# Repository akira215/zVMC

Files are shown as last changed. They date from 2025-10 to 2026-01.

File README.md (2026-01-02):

# zVMC
Driving ALDES controlled mechanical ventilation using Modbus, embedded sofware on dedicated PCB using ESP32C6 µC

# Description

This repository contain all the development for an electronic device that will monitor ALDES VMC Inspirair using zigbee to transmit data to a coordinator. It contains: 
 * A PCB design [PCB design](PCB/README.md)
 * An enclosure design to be printed in 3D [Enclosure design](3Dprint/README.md)
 * Source code of the embedded software on the board (in an ESP32C6 µC)
 * An External converter for Zigbee2MQTT service [external converter](external_converters)

# Principle

The board will collect data from various sensors surch as:
 * Upstream static pressure (pump side)
 * Downstream static pressure (home side) - difference between upstream and downstream static pressure is used to estimate filters clogging
 * Water level sensor, to estimate the available water volume in the tank
 * water pulse meter to count the consumption in the home
 * Additionally on board temperature sensor could be monitor

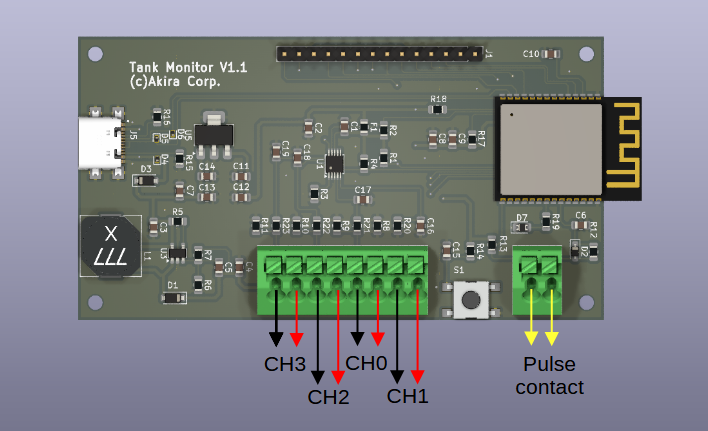
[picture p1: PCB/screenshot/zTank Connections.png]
zTank connections
 

 The 3 first sensors shall be 4-20mA sensor directly connected to the board. The water counter shall be a dry contact meter, connected to the board

 All these sensors have a calibration factor that can be updated directly form Zigbee2MQTT GUI. To avoid losing calibration, the device itself will keep updated theses factor in its Non Volatile Storage.

z2m settings (specific)

A 4-20mA input is available for any other futher sensor requirement. Adding a sensor will require to :
 * Update the embedded software
 * Update the external converter on Zigbee2MQTT side

## Usage

  * Short press button to join the zigbee network (coordinator shall grant pairing) -> LED shall flash, until network is joined, it then shutoff
  * Long press button to leave network. When the LED is fixed on, the device is not connected to the network neither is trying to join

## Sensor selection

### Upstream and downstream static pressure

  Regular pressure transmitter are not so expensive and efficient for that purpose. These 2 sensors shall have a measured range according to installation pressure. In regular network, pressure is limited to 3 bars, so selecting a sensor 0-5 bars seems a good choice. If the upper value is higher, the resolution of the measurement will be less as the ADC converter resolution is fixed.

  The shunt to convert current to tension for the ADC converter is 133R, and Imax for the sensor @max range will be 20mA so Umax for ADS1115 will be 2.66V (U=R*I). 5 bars = 500 kPa, so the calibration factor shall be 500 kPa / 2.66V = 187.97 kPa/V. Of course this factor shall be adjusted by measuring at the same location of one sensor the pressure, and correcting the reading of the sensor, but this short computation can help to start setting up calibration factor

### Water level

  Whatever technology of sensor could be used as soon as its output is 4-20mA current. Tests have been done using submerged differential pressure sensor, with the balance pipe to get the atmospheric pressure that run with the electrical cable, they worked properly. The range of this sensor shall be in accordance with the depth of the tank. The output value of Zigbee2MQTT will be a % of depth (meaning 100% when tank is full). Depending on the shape and cross section of the tank, this could be converted to a volume directly in the Z2M external converter, or outside Z2M in another software.

  The shunt to convert current to tension for the ADC converter is 133R, and Imax for the sensor @max range will be 20mA so Umax for ADS1115 will be 2.66V (U=R*I). fFr 100% the calibration factor shall be 100% / 2.66V = 37.594 %/V. Of course this factor shall be adjusted when tank is full to read 100% in the Zigbee2MQTT output.

### Water pulse counter

  The water meter shall send a pulse each XX L, whatever XX is. It is expected to have a dry contact that switch on and off each pulse. Hardware debouncer has been implemented for a particular counter, measuring bouncing using an oscilloscope. Computation of this RC filter has been provided here:
  [Spreadsheet](<PCB/2024-06-29 Comput.ods>)
    
  The kFactor to be set up in Zigbee2MQTT is only the L per pulse of the counter.

## Zigbee2MQTT integration

### External converter

External converter shall be loaded according to Zigbee2MQTT instructions:

[Zigbee2MQTT external converters](https://www.zigbee2mqtt.io/advanced/more/external_converters.html)

Restart Zigbee2MQTT `Webpage > Settings > Tools > Restart Zigbee2MQTT`

### Pairing zTank device

If the LED is fixed on, short press one time on the button, this will put the device in pairing mode.
Device is in Pairing Mode when the LED flahes quickly. 

Put Coordinator (or other device) in pairing mode using Zigbee2MQTT GUI (antenna symbol on the upper right of the screen with mention `All`)

After a short time, LED shall stop flashing. When LED is off, device is paired. You can check on Zigbee2MQTT device list

### Device icon

To add an icon in Zigbee2MQTT GUI, create a folder named `device_icon` in the root of Zigbee2MQTT docker installation (folder containing `configuration.yml`). In that foler, put the `zTank_icon.png` file contained in the `img` directory of this repository.

On Zigbee2MQTT GUI, go to `Devices` list and click on the device. Go to `Settings` tab and scroll down to the `icon` box.
Put `device_icons/zTank_icon.png` in that box. Icon shall be visible on Zigbee2MQTT GUI.

### Reporting

To develop*******************************************************************

## Build Instructions

The embedded software required `esp-ash-components`:

```
git submodule add https://github.com/akira215/esp-ash-components.git components
```

Create a partition.csv for zigbee and configure menuconfig with custom partition table (shall be done by default)

## Remote USB over IP to debug

### Server side using raspberry Pi

Install package:

```
sudo apt install usbip
```

Install drivers and let them run at start:

```
sudo -i
modprobe usbip_host
echo 'usbip_host' >> /etc/modules
```

List usb devices:

```
usbip list -l
```

Create start and stop scripts:

```
nano /usr/sbin/usbip_start.sh
```

```
#! /bin/bash

usb1='303a:1001'
# usb2='xxx'

/usr/sbin/usbip bind --$(/usr/sbin/usbip list -p -l | grep '#usbid='$usb1'#' | cut '-d#' -f1)
#/usr/sbin/usbip bind --$(/usr/sbin/usbip list -p -l | grep '#usbid='$usb2'#' | cut '-d#' -f1)

```

```
nano /usr/sbin/usbip_stop.sh
```

```
#! /bin/bash

usb1='303a:1001'
# usb2='xxx'

/usr/sbin/usbip unbind --$(/usr/sbin/usbip list -p -l | grep '#usbid='$usb1'#' | cut '-d#' -f1)
#/usr/sbin/usbip unbind --$(/usr/sbin/usbip list -p -l | grep '#usbid='$usb2'#' | cut '-d#' -f1)
killall usbipd
```

Turn them executables:

```
chmod +x /usr/sbin/usbip_start.sh
chmod +x /usr/sbin/usbip_stop.sh
```

Test the scripts:

```
. /usr/sbin/usbip_start.sh
. /usr/sbin/usbip_stop.sh
```

Create a service:

```
nano /lib/systemd/system/usbipd.service
```

```
[Unit]
Description=usbip host daemon
After=network.target

[Service]
Type=forking
ExecStart=/usr/sbin/usbipd -D
ExecStartPost=/bin/sh -c '/usr/sbin/usbip_start.sh'
ExecStop=/bin/sh -c '/usr/sbin/usbip_stop.sh'

[Install]
WantedBy=multi-user.target
```

Start the service at boot:
let system know about that service

```
systemctl --system daemon-reload
```

to start service at boot

```
systemctl enable usbipd.service
```

and start service, check status:

```
systemctl start usbipd.service
systemctl status usbipd.service
```

### Client side Windows 11

Create a restore point on the system

Install OSSign release of https://github.com/vadimgrn/usbip-win2 :

https://github.com/OSSign/vadimgrn--usbip-win2/releases

run the GUI to find the device !

## Configuration

Configuration is available in `menuconfig` in the `Project setting` section:

### Pin Layout

  This section refer to hardware connection of LED button and volume meter. <span style="color:red">**These settings shall not be changed unless new hardware is developped.**</span>

pin layout

### Zigbee endpoints

  This section refer to the endpoint for each sensor of the device. Any change in this number require to update the external converter accordingly

Zigbee endpoints

  And in Zigbee2MQTT external converter:

External converter

### Zigbee device

  Zigbee stack has been sized doing extensive tests. <span style="color:red">**This setting shall not be changed.**</span>

Zigbee device

### ADS Pin Layout

  This section refer to hardware connection of ADS1115 converter to µC pin. <span style="color:red">**These settings shall not be changed unless new hardware is developped.**</span>

ADS pin layout

### ADS Converter config

  The first 3 inputs refer to the channel in which each sensor is connected. Take care that channel are not implemented on the connector in a logical order, so please refer to pictures that describe which pins of the connector is connected to which ADC channel (and polarity for sensors)

  The delay between 2 queries of ADS is the update rate of the measurement. Between 2 measurement, ADS is put in sleep to optimize consumption. Take care that driver will trigger one conversion for each channel, so there is a minimal time between 2 queries, depending on the resolution set for the ADS.

  The delay between 2 queries of temperature is the update rate of the measurement of the internal µC temperature sensor.

ADS converter config

## Current Status

Still work in progress, but is completely running. All bugs 
could be reported to try to improve it.

## PCB design

[PCB design](PCB/README.md)

## Enclosure design design

[Enclosure design](3Dprint/README.md)

## Caveats

### To be developped

OTA update

## Usage and Examples

## Changes

### New in version 0.0.0

## Credits

 * [Zigbee2MQTT](https://github.com/Koenkk/zigbee2mqtt)

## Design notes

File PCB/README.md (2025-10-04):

# zTank PCB
A dedicated PCB using ESP32C6 µC as been designed to optimize reliability and costs.

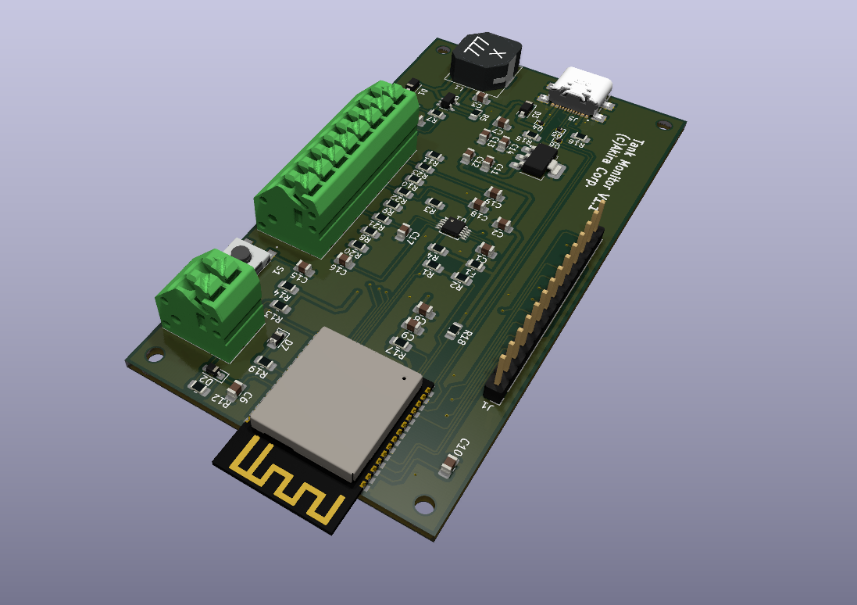
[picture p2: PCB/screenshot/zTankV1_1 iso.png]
Iso view of zTank PCB


## Tools

 The design of the PCB has been done with KiCad 9.0. Particular footprint and 3D STEP file are included in the `/footprints` folder for sake of maintenance

## Design

 The design is based on ESP32C6 WROOM with the following peripherials:
 * USB for power, flash device and output serial debug / info.
 * Powering circuit is done using MCP1826S 
 * A 4-20mA loop is built based on a LM2735X (1.6MHz) to raise voltage to about 20V
 * 4 channels 4-20mA sensors is provided and converted using ADS1115IDGS. It communicate with µC with i2c port
 * a debounced contact is provided for pulse counter
 * A push button is also provided for very simple HMI
 * PCB is also equipped by a LED for simpl HMI
 * Finally PCB is equipped with header that can be used for a touchscreen device in case of future needs (software lib already written and tested)

 Component size has been selected to 0805, except ESD protective diodes that are smaller.

### USB

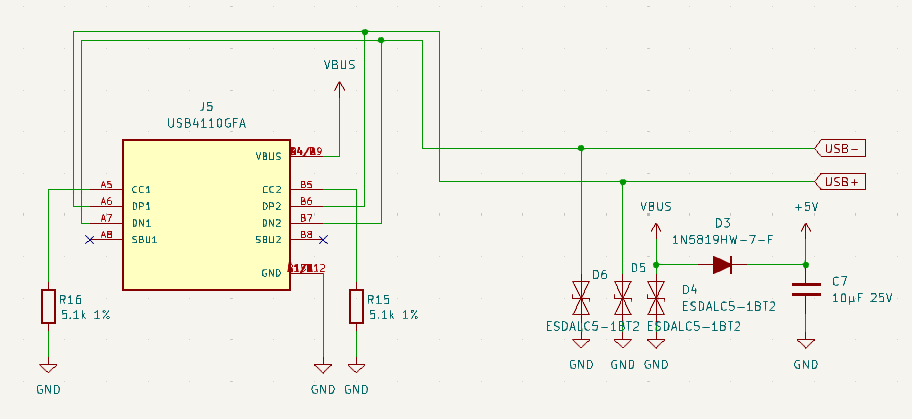
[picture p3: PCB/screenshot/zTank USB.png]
USB schematic
  

  USB socket is grounded to the main ground planes (2 sides).
  USB Lines `USB-` and `USB+` are directly connected to ESP32C6 to flash and monitor µC.
  `VBUS` is used to provide `+5V` (which is in fact lower than +5V) via a protective diode `D3`.

  All this 3 lines are protected by ESD protective diode.

### Voltage regulator

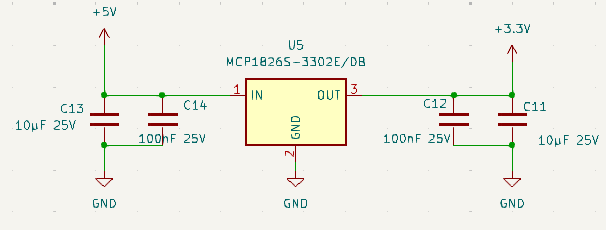
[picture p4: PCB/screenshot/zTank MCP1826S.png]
Regulator schematic
  

  All the board is powered using `+3.3V`. This voltage is provided by a fixed low-voltage regulator MCP1826S-3302E that can provide up to 1000mA.
  Fixed voltage regulator requires only few external component, in this case only capacitors are installed as per datasheet.

### 4-20mA Voltage circuit

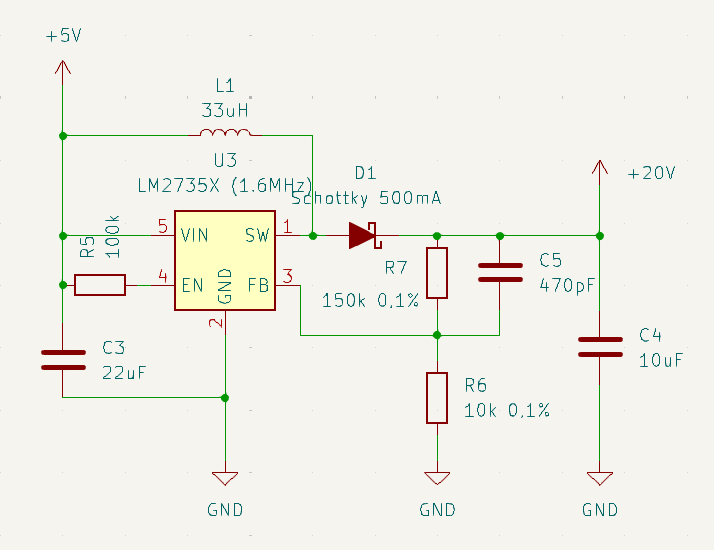
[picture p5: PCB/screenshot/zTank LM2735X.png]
LM2735X schematic
  

  To avoid noise on lines and due to voltage drop at each stage, 4-20mA loop voltage shall be at around 20V. Care shall be taken when changing this voltage as it may require adjustment (in the shunt values for instance) to avoid damaging other components.

  This voltage is produced from `+5V` using a boost type regulator LM2735X (@1.6MHz). Computation of the external components are provided in the LibreOffice Spreadsheet [PCB comput spreadsheet](<2024-06-29 Comput.ods>). A 33µH inductance has been selected to get a clean output voltage to avoid noise on sensors line.

### 4-20mA conversion

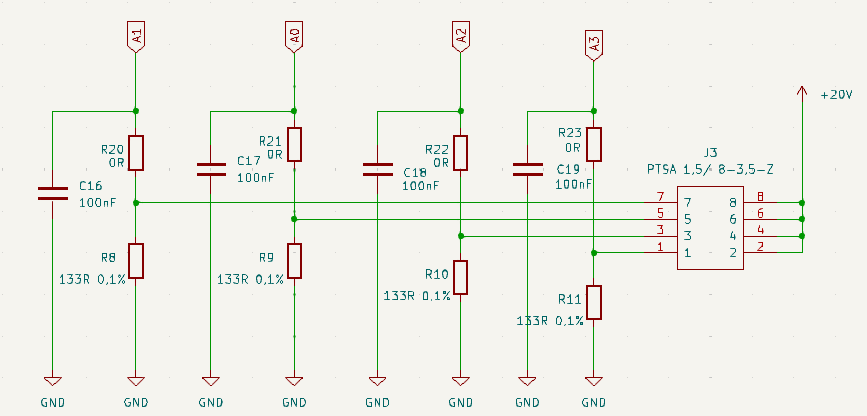
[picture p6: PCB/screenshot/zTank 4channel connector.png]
4 channel connector schematic
 

  4 channels are available via Phoenix contact 8 poles connector. Each channel input current is injected in a 133R shunt (low tolerance resistor) to output a voltage below 3.3V. A 100nF capacitor is provided to reduce noise.

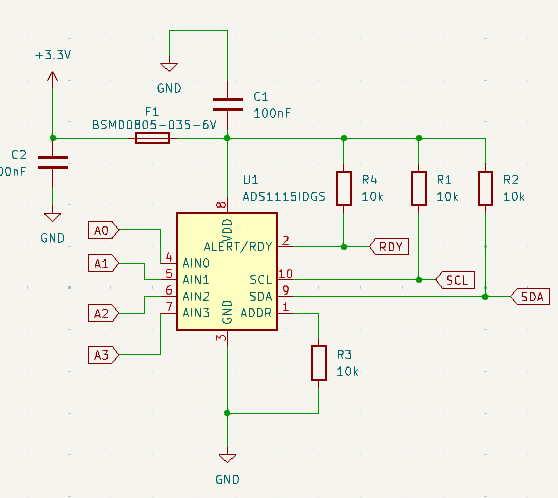
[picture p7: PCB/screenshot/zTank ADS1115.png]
ADS1115 schematic
  

  Each channel voltage is then converted in a digital signal using an ADS1115IDGS, that communicate with µC using i2c protocol. A ready pin is used to trigger an interrupt to the µC when data are available.
  External components are:
   * 10k resistor connected to the ground for the address of the device (only one on board so gnd is the common one)
   * 10k pull-up resistor on each signal (`SCL`, `SDA`, `RDY`) connected to µC
   * Decoupling capacitor for power lines and rearmable fuse to protect circuit

### Debounced contact

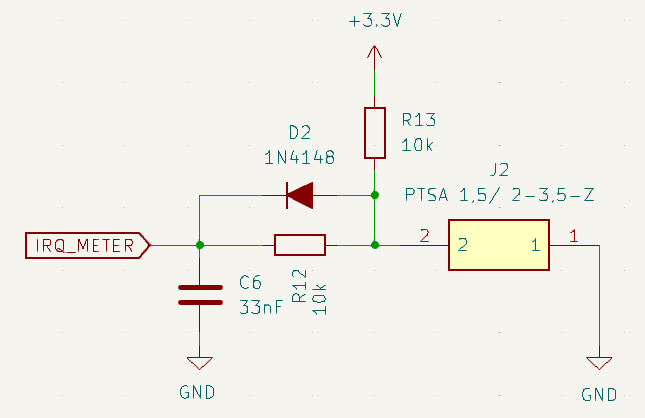
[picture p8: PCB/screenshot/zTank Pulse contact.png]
Debounced pulse schematic


An harware RC filter has been set up on this input to avoid false triggering. The computation of this filter is detailed in the spreadsheet file [PCB comput spreadsheet](<2024-06-29 Comput.ods>), bouncing duration has been measured using an oscilloscope in a unique water meter equiped with dry contact pulse output. It may be required to adjust this filter if the water meter seems to input false pulse to the µC. 

The only other component is a pull-up resistor to not let a float input.

### µC ESP32C6 WROOM

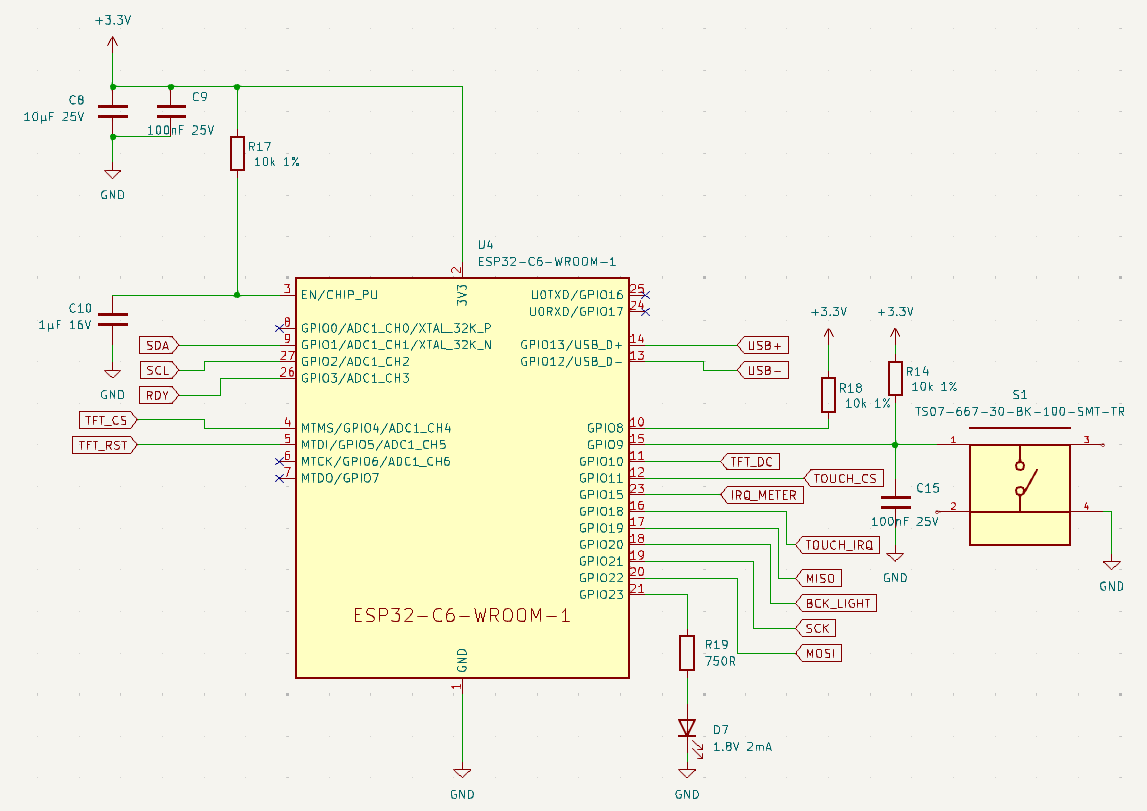
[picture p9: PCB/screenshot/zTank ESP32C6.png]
µC schematic


ESP32C6 power up is done using decoupling capacitor (10µF // 100nF).

The `EN` pin is driven to the `+3.3V` to enable the µC. 

`GPIO9` shall be pulled up to `+3.3V` to set the µC in normal execution mode (instead of ROM serial bootloader when `GPIO9` is pulled to the ground). Despite the doc says that it has an internal pull-up, µC will not boot normally after reporg if not driven to `+3.3V`.

`GPIO8` shall be driven to `+3.3V` as doc says, in order to enter the serial bootloader reliably.

### Push Button

Push button has been connected to `GPIO9`, so it can be used to boot/flash device by driving the pin low. Indeed, no operation is required on this button to flash µC using USB directly, and push button is used by software for HMI purpose.

### Led

A led is connected to `GPIO23` for HMI purpose as well. Resistor has been calculated according to LED spec to grant the required current.

### Header

A header is available to drive a touchscreen if required. It has not been integrated in the enclosure of this repo. It was planned and tested using a ILI9341 TFT touchscreen.

## PCB fabrication

Gerber files are included for fabrication. A batch of PCB has been produced by JLCPCB with the following configuration:

|Base Material |	FR-4	 | Layers |	2 |
|---|---|---|---|
|Dimension |	49 mm* 91 mm | PCB Qty |	20 |
|Product Type |	Industrial/Consumer electronics | Different Design |	1 |
|Delivery Format |	Single PCB	 | PCB Thickness |	1.6mm |
|Specify Stackup |	no	 | Layer Sequence | |	
|PCB Color |	Purple	 | Silkscreen |	White |
|Material Type |	TG135	 | Via Covering |	Tented |
|Surface Finish |	ENIG Gold Thickness: 1U"	 | Deburring/Edge rounding |	No |
|Outer Copper Weight  |	1 oz	 | Gold Fingers |	No |
|Electrical Test |	Flying Probe Fully Test	 | Castellated Holes |	no |
|Edge Plating |	No	 | Mark on PCB	 | Order Number |
|Blind Slot |	No	 | Min via hole size/diameter |	0.3mm/(0.4/0.45mm)|
|4-Wire Kelvin Test |	No	 | Paper between PCBs |	No |
|Appearance Quality |	IPC Class 2 Standard	 | Confirm Production file |	No |
|Silkscreen Technology|	Ink-jet/Screen Printing Silkscreen | Package Box |	With JLCPCB logo  |
|Inspection Report |	No	 | Board Outline Tolerance |	±0.2mm(Regular) |
|UL Marking |	No	 | Countersink Hole |	No |

## Assembly

A stencil as been produced by JLCPCB, so the assembly has been done using solder paste, manually placing components, and reflow is done using an hot plate.

The components that generate issues during that process are:
 * USB connector `J5` : often some bridges are created due to the high density of pin. It has to be manually fixed
 * ESD protection diodes `D4`, `D5` & `D6`: are they are really small and light, they moved during the reflow process. It has to be manually fixed with a soldering iron, as hot air gun make them move anyway whaterver the airflow is
 * Care should be taken on the pin of ADS converter `U1`(bridges) and µC `U4` (alke of solder)
 * Obviously connector `J1`, `J2` and `J3` have to be solded manually

## Usage

For routing simplicity, 4-20mA channels are not reparted logically on the board, please consider the scheme here below.

Debounced pulse contact don't have polarity.

Board connectors

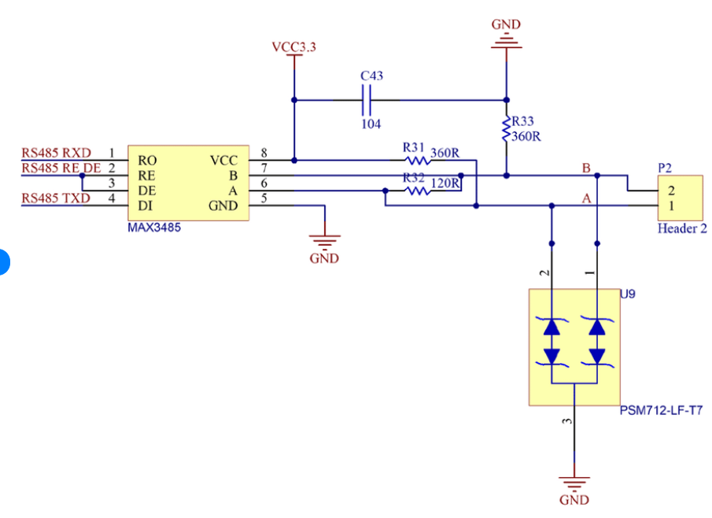
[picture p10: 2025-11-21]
00-Docs/MAX3485 schematic.png

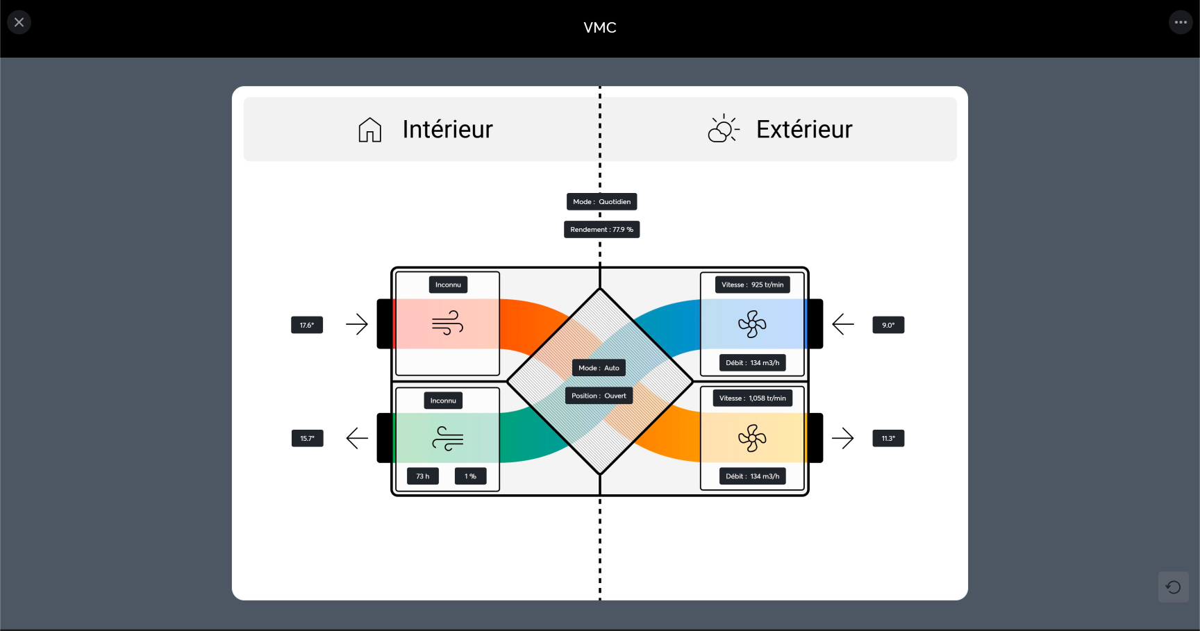
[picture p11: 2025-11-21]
00-Docs/Schema.jpg

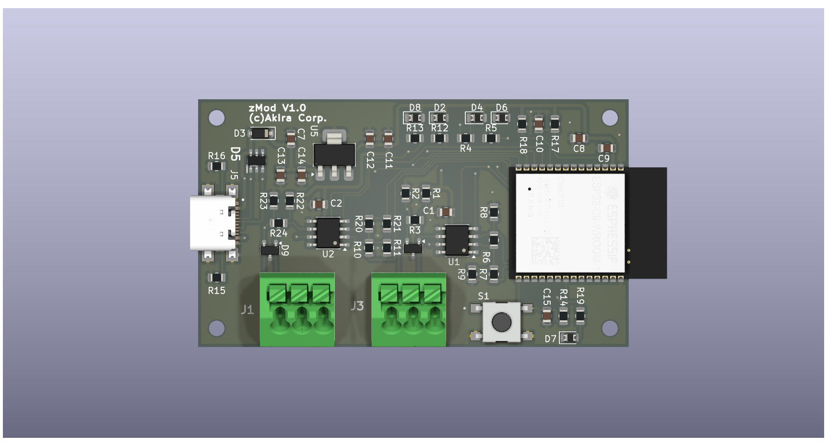
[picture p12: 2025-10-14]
PCB/screenshot/zVMC_PCB top.png

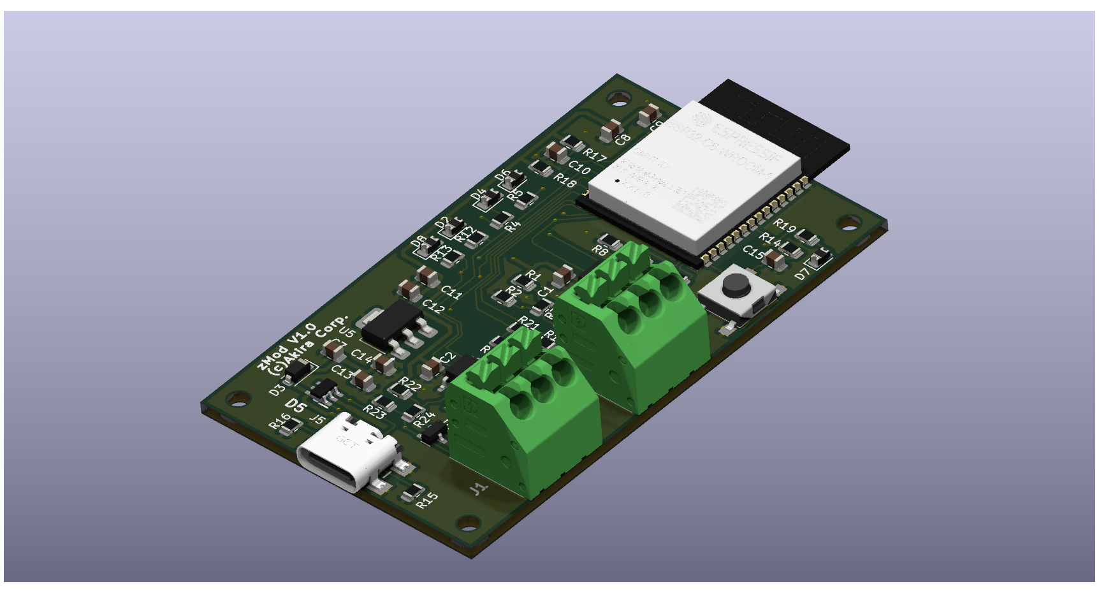
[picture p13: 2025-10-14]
PCB/screenshot/zVMC_PCB iso.png

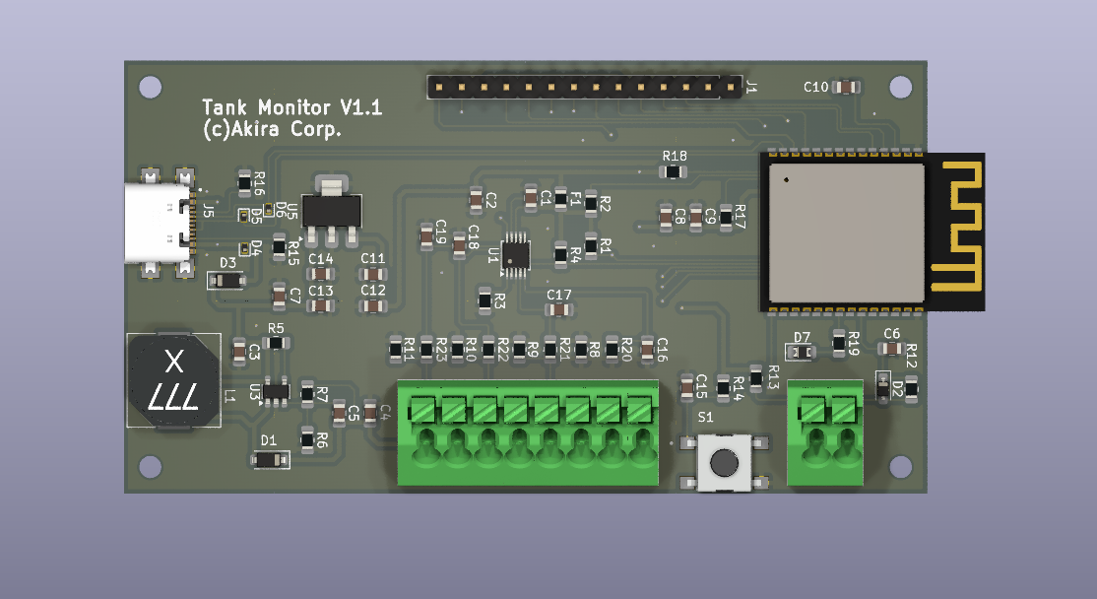
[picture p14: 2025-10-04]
PCB/screenshot/zTankV1_1 top-parall.png

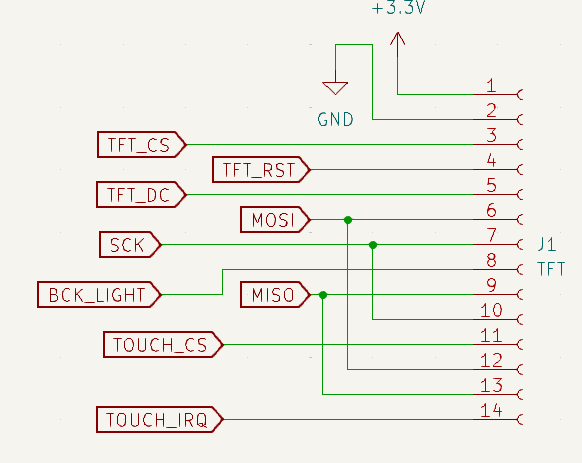
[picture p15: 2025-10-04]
PCB/screenshot/zTank Header.png

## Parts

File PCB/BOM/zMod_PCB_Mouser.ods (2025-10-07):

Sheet: Mouser
ZMOD
Mouser No | Mfr. No | Manufacturer | Customer No | Description | RoHS | Lifecycle | Order Qty. | Price (EUR) | Ext.: (EUR)
179-TS0766730BK100SM | TS07-667-30-BK-100-SMT-TR | Same Sky |  | Tactile Switches 6 x 6.7 mm, 3 mm Act Height, 100 gf, Black, Surface Mount, TR, SPST, | RoHS Compliant |  | 1 | 0,172 € | 0,17 €
621-1N5819HW-F | 1N5819HW-7-F | Diodes Incorporated |  | Schottky Diodes & Rectifiers Vr/40V Io/1A T/R | RoHS Compliant |  | 1 | 0,232 € | 0,23 €
80-C0805C106K3P | C0805C106K3PACTU | KEMET |  | Multilayer Ceramic Capacitors MLCC - SMD/SMT 25V 10uF X5R 0805 10% | RoHS Compliant |  | 4 | 0,189 € | 0,76 €
80-C0805C105K4R | C0805C105K4RACTU | KEMET |  | Multilayer Ceramic Capacitors MLCC - SMD/SMT 16V 1uF X7R 0805 10% | RoHS Compliant |  | 1 | 0,155 € | 0,16 €
80-C0805C104K5R | C0805C104K5RACTU | KEMET |  | Multilayer Ceramic Capacitors MLCC - SMD/SMT 50V 0.1uF X7R 0805 10% | RoHS Compliant |  | 6 | 0,086 € | 0,52 €
604-APT2012LSECKJ3RV | APT2012LSECK/J3-PRV | Kingbright |  | Single Colour LEDs 2.0X1.2MM LOW CRNT | RoHS Compliant |  | 1 | 0,456 € | 0,46 €
640-USB4110-GF-A | USB4110-GF-A | GCT |  | USB Connectors USB Type C, 2.0, Rec, SMT , G/F, RA , Top Mnt, T & R | RoHS Compliant |  | 1 | 1,07 € | 1,07 €
356-ESP32C6WROOM1N8 | ESP32-C6-WROOM-1-N8 | Espressif |  | Multiprotocol Modules 8 MB (Quad SPI), 32-bit RISC-V Embedded Module | RoHS Compliant |  | 1 | 5,41 € | 5,41 €
579-MCP1826S-3302EDB | MCP1826S-3302E/DB | Microchip |  | LDO Voltage Regulators 1A CMOS LDO Vout 3.3V ETR | RoHS Compliant |  | 1 | 0,783 € | 0,78 €
651-1985205 | 1985205 | Phoenix Contact |  | Fixed Terminal Blocks PTSA 1.5/3-3.5-Z | RoHS Compliant |  | 2 | 0,439 € | 0,88 €
604-APT2012LZGCK | APT2012LZGCK | Kingbright |  | Single Colour LEDs 2.0X1.2MM LOW CRNT | RoHS Compliant |  | 2 | 0,378 € | 0,76 €
604-APT2012LSYCKJ3RV | APT2012LSYCK/J3-PRV | Kingbright |  | Single Colour LEDs 2.0X1.2MM LOW CRNT | RoHS Compliant |  | 2 | 0,456 € | 0,91 €
667-ERA-6AEB121V | ERA-6AEB121V | Panasonic |  | Thin Film Resistors - SMD 0805 1/8W 120ohms | RoHS Compliant By Exemption |  | 2 | 0,086 € | 0,17 €
667-ERA-6AEB751V | ERA-6AEB751V | Panasonic |  | Thin Film Resistors - SMD 0805 1/8W 750ohms | RoHS Compliant By Exemption |  | 3 | 0,086 € | 0,26 €
667-ERA-6AEB331V | ERA-6AEB331V | Panasonic |  | Thin Film Resistors - SMD 0805 1/8W 330ohms | RoHS Compliant By Exemption |  | 2 | 0,086 € | 0,17 €
667-ERA-6AEB103V | ERA-6AEB103V | Panasonic |  | Thin Film Resistors - SMD 0805 1/8W 10Kohms | RoHS Compliant By Exemption |  | 7 | 0,086 € | 0,60 €
667-ERJ-6GEY0R00V | ERJ-6GEY0R00V | Panasonic |  | Thick Film Resistors - SMD 0805 Zero Ohms Jumper AEC-Q200 | RoHS Compliant By Exemption |  | 8 | 0,086 € | 0,69 €
667-ERA-6AEB512V | ERA-6AEB512V | Panasonic |  | Thin Film Resistors - SMD 0805 5.1Kohm 1/8W .1% 25ppm | RoHS Compliant By Exemption |  | 2 | 0,086 € | 0,17 €
771-BZA408BT/R | BZA408B,115 | Nexperia |  | ESD Protection Diodes / TVS Diodes ESD 5V BI | RoHS Compliant |  | 1 | 0,387 € | 0,39 €
968-ISL3178EIBZ | ISL3178EIBZ | Renesas Electronics |  | RS-422/RS-485 Interface IC 8LD -40+85 3V RS-485 1/2 DUP 10M | RoHS Compliant |  | 2 | 1,73 € | 3,46 €
652-CDSOT23-SM712 | CDSOT23-SM712 | Bourns |  | ESD Protection Diodes / TVS Diodes SOT-23 7V400W Low Capacitance | RoHS Compliant |  | 2 | 0,894 € | 1,79 €

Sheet: zMod_PCB
Reference | Qty | Value | Footprint | DNP | Datasheet
C1,C2,C9,C12,C14,C15 | 6 | 100nF 25V | Capacitor_SMD:C_0805_2012Metric |  | 35V X5R
C7,C8,C11,C13 | 4 | 10µF 25V | Capacitor_SMD:C_0805_2012Metric |  | 35V X5R
C10 | 1 | 1µF 16V | Capacitor_SMD:C_0805_2012Metric |  | 35V X5R
D1,D9 | 2 | CDSOT23-SM712 | Package_TO_SOT_SMD:SOT-23 |  | https://www.littelfuse.com/~/media/electronics/datasheets/tvs_diode_arrays/littelfuse_tvs_diode_array_sm712_datasheet.pdf.pdf
D2,D6 | 2 | Green 1.8V 2mA | Diode_SMD:D_0805_2012Metric |  | ~
D3 | 1 | 1N5819HW-7-F | Diode_SMD:D_SOD-123 |  | ~
D4,D8 | 2 | Yellow 1.8V 2mA | Diode_SMD:D_0805_2012Metric_Pad1.15x1.40mm_HandSolder |  | ~
D5 | 1 | BZA408B,125 | zVMCFootprints:SOT95P275X110-6N |  | https://assets.nexperia.com/documents/data-sheet/BZA408B.pdf
D7 | 1 | Red 1.8V 2mA | Diode_SMD:D_0805_2012Metric |  | ~
J1,J3 | 2 | PTSA 1.5/3-3.5-Z | zVMCFootprints:Phoenix Contact PTSA 3 |  | https://componentsearchengine.com/Datasheets/1/1985205.pdf
J5 | 1 | USB4110GFA | zVMCFootprints:GCT_USB4110GFA |  | https://www.mouser.com/catalog/specsheets/GCT_USB4110%20Product%20Drawing%20-%2020k%20cycles.pdf
R1,R2,R22,R23 | 4 | 10k | Resistor_SMD:R_0805_2012Metric |  | ~
R3,R24 | 2 | 120R | Resistor_SMD:R_0805_2012Metric |  | ~
R4,R13,R19 | 3 | 750R | Resistor_SMD:R_0805_2012Metric |  | ~
R5,R12 | 2 | 330R | Resistor_SMD:R_0805_2012Metric |  | ~
R6,R7,R8,R9,R10,R11,R20,R21 | 8 | 0R | Resistor_SMD:R_0805_2012Metric |  | ~
R14,R17,R18 | 3 | 10k 1% | Resistor_SMD:R_0805_2012Metric |  | ~
R15,R16 | 2 | 5.1k 1% | Resistor_SMD:R_0805_2012Metric |  | ~
S1 | 1 | TS07-667-30-BK-100-SMT-TR | zVMCFootprints:CUI switch SW_TS07-667-30-BK-100-SMT-TR |  | https://www.mouser.fr/datasheet/3/6118/1/ts07.pdf
U1,U2 | 2 | MAX3485 | Package_SO:SOIC-8_3.9x4.9mm_P1.27mm |  | https://datasheets.maximintegrated.com/en/ds/MAX3483-MAX3491.pdf
U4 | 1 | ESP32-C6-WROOM-1 | zVMCFootprints:ESP32-C6-WROOM-1 |  | https://www.espressif.com/sites/default/files/documentation/esp32-c6-wroom-1_wroom-1u_datasheet_en.pdf
U5 | 1 | MCP1826S-3302E/DB | Package_TO_SOT_SMD:SOT-223-3_TabPin2 |  | https://www.analog.com/media/en/technical-documentation/data-sheets/1963aff.pdf

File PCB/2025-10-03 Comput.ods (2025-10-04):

Resistor computation for LED
 | Power supply | Vf | 3,3 | V
 | Vf [V] | I [mA] | Ures [V] | R [Ω] | Ref | Link
LED Red | 1,8 | 2 | 1,5 | 750 | APT2012LSECK/J3-PRV | https://www.mouser.fr/ProductDetail/Kingbright/APT2012LSECK-J3-PRV?qs=6oMev5NRZMEkGJkKIsAalQ%3D%3D
LED Green | 2,65 | 2 | 0,65 | 325 | APT2012LZGCK | https://www.mouser.fr/ProductDetail/Kingbright/APT2012LZGCK?qs=6oMev5NRZMHOosFiXb%2F3qw%3D%3D
LED Yellow | 1,85 | 2 | 1,45 | 725 | APT2012LSYCK/J3-PRV | https://www.mouser.fr/ProductDetail/Kingbright/APT2012LSYCK-J3-PRV?qs=6oMev5NRZMGoWLCc4feqUg%3D%3D
LED Blue | 2,65 | 2 | 0,65 | 325 | APT2012LVBC/D | https://www.mouser.fr/ProductDetail/Kingbright/APT2012LVBC-D?qs=6oMev5NRZMGErJYT6KZLXg%3D%3D
LED Orange | 1,8 | 2 | 1,5 | 750 | APT2012LSECK/J4-PRV | https://www.mouser.fr/ProductDetail/Kingbright/APT2012LSECK-J4-PRV?qs=6oMev5NRZMH7xdB4zkudcw%3D%3D
 |  |  |  |  |  |  | OOPPPPPP¨TURTTHHJJKKL%MM%%%%%M¨%MLVJGLGUNUUPPGO PI./IH U?JJFV ? BNBNUTFTJTUJKGKG

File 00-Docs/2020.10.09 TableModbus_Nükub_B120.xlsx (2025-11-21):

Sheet: Feuil1
Table Modbus Nükub_B120 @ 09/10/2020
 | Bus Config | Type | rtu | baudrate | 9600 | data | 8 | parity | none | stop | 1 | Port | COM5
 | Equipment Cfg |  | name | Nükub_B120 | slave | 2 | Prefix | modbus_NUKUB_ | getPrefix | get | setPrefix | set
 | Catégorie | Adresse (Décimal) | Adresse (Hexa) | Nom Data | Taille (Words) | Type (décodage) | Lecture (nv requis) | Ecriture (nv requis) | Valeur Min | Valeur Max | Valeur par défaut | Unité | Coefficient | Soft ? | Remarques
 | Identification
 |  | 1 | $1 | Code SAP Produit | 2 | uint | 0 | 4 |  |  |  |  |  | Oui | Enum = "11023471:VEX 40 T CLASSIC 3471/11023472:VEX 40 T PREMIUM 3472/11023473:INSPIRAIR TOP 300 CLASSIC 3473/11023474:INSPIRAIR TOP 300 PREMIUM 3474/11023475:INSPIRAIR TOP 450 CLASSIC 3475/11023476:INSPIRAIR TOP 450 PREMIUM 3476/11023477:INSPIRAIR TOP 300 ERV 3477/11023478:INSPIRAIR TOP 450 ERV 3478"
 |  | 3 | $3 | SN du Produit | 4 | uint | 0 | 4 |  |  |  |  |  | Oui
 |  | 7 | $7 | Date Test Carte | 1 | uint | 0 | 5 |  |  |  |  |  | Oui
 |  | 8 | $8 | Code SAP Carte | 2 | uint | 0 | 5 |  |  |  |  |  | Oui | Enum = "11029476:Classic/11029475:Pression"
 |  | 10 | $A | SN Carte Principale | 2 | uint | 0 | 5 |  |  |  |  |  | Oui
 |  | 12 | $C | VersionSoft | 1 | uint | 0 | N/A |  |  |  |  |  | Oui
 |  | 13 | $D | TargetId | 1 | uint | 0 | N/A |  |  |  |  |  | Oui | Enum = "0:Europe/1:Chine"
 |  | 14 | $E | CRC Soft | 2 | uint | 0 | N/A |  |  |  |  |  | Oui
 |  | 16 | $10 | UserLevel | 1 | uint | N/A | 0 |  |  |  |  |  | Oui | Enum = "0:Normal/2345:Lvl_1/12054:Lvl_2/34102:Lvl_3"
 |  | 17 | $11 | ID Modbus User | 1 | uint | 0 | 0 |  |  |  |  |  | Oui
 |  | 20 | $14 | Save Params | 1 | uint | N/A | 0 |  |  |  |  |  | Oui | Enum = "0:Idle/22577:Product Params/31028:Factory Params"
 |  | 21 | $15 | Model Size | 1 | uint | 0 | N/A |  |  |  |  |  | Oui | Enum = "0:Inconnu/16:Nükub 300/17:Nukub 450/65535:Indéterminé"
 | Réglages Usine
 |  | 32 | $20 | ProductConfigStatus | 1 | uint | 0 | 2 |  |  |  |  |  | Oui | Enum = "3:Product Complete/2:Config Ready/1:Product Ready/0:Board Ready/9545:Start Service"
 |  | 33 | $21 | ReInit Factory | 1 | uint | N/A | 2 |  |  |  |  |  | Oui | Enum = "0:NoAction/18213:ConfigReset"
 |  | 34 | $22 | ProductId | 1 | uint | 0 | 2 |  |  |  |  |  | Oui | Enum = "3471:VEX 40 T CLASSIC 11023471/3472:VEX 40 T PREMIUM 11023472/3473:INSPIRAIR TOP 300 CLASSIC 11023473/3474:INSPIRAIR TOP 300 PREMIUM 11023474/3475:INSPIRAIR TOP 450 CLASSIC 11023475/3476:INSPIRAIR TOP 450 PREMIUM 11023476/3477:INSPIRAIR TOP 300 ERV 11023477/3478:INSPIRAIR TOP 450 ERV 11023478"
 |  | 35 | $23 | FanCmdTable | 1 | uint | 0 | 3 |  |  |  |  |  | Oui | Enum = "1:Table 300/2:Table 450"
 |  | 36 | $24 | DefaultFilterInsufflation | 1 | uint | 0 | N/A |  |  |  |  |  | Oui | Enum = "1:Poussières/2:Pollens/3:Particules/4:Particules Fines/5:Bactéries/6:COV/0:Indéterminé"
 |  | 37 | $25 | HR_LED_IHM Flags | 1 | uint | 0 | N/A |  |  |  |  |  | Oui | Enum = "1:HR Requise/2:Led RGB Autorisée/4:IHM Requise/3:HR + Led RGB/5:HR + IHM requises/6:Led + IHM/7:HR + Led RGB + IHM/0:Aucun Flag"
 |  | 38 | $26 | Débit Min | 1 | uint | 0 | N/A |  |  |  | m³/h |  | Oui
 |  | 39 | $27 | Débit Max | 1 | uint | 0 | N/A |  |  |  | m³/h |  | Oui
 |  | 40 | $28 | Débit L0 par défaut | 1 | uint | 0 | N/A |  |  |  | m³/h |  | Oui
 |  | 41 | $29 | Débit L1 par défaut | 1 | uint | 0 | N/A |  |  |  | m³/h |  | Oui
 |  | 42 | $2A | Débit L2 par défaut | 1 | uint | 0 | N/A |  |  |  | m³/h |  | Oui
 |  | 43 | $2B | Débit L3 par défaut | 1 | uint | 0 | N/A |  |  |  | m³/h |  | Oui
 |  | 44 | $2C | Default Language | 1 | uint | 0 | N/A |  |  |  |  |  | Oui | Enum = "1:Français/2:Anglais/3:Allemand/4:Espagnol/5:Italien/6:Néerlandais/7:Danois/0:Inconnu"
 |  | 45 | $2D | Default Country | 1 | uint | 0 | N/A |  |  |  |  |  | Oui | Enum = "1:France/2:Angleterre/3:Allemagne/4:Espagne/5:Italie/6:Benelux/7:Danemark/10:Nord-Amérique/15:Chine/0:Inconnu"
 |  | 48 | $30 | Default Timer L0 | 1 | uint | 0 | N/A |  |  |  | jours |  | Oui
 |  | 49 | $31 | Default Timer L2 | 1 | uint | 0 | N/A |  |  |  | mn |  | Oui
 |  | 50 | $32 | Default Timer L3 | 1 | uint | 0 | N/A |  |  |  | heures |  | Oui
 | Fonctionnement GTB
 |  | 256 | $100 | Mode Régul | 1 | uint | 0 | 0 | 0 | 2 | 0 |  |  | Oui | Enum = "0:Débit/1:Hygro/2:Vitesse"
 |  | 257 | $101 | Demande User | 1 | uint | 0 | 0 | 0 | 4 | 1 |  |  | Oui | Enum = "1:Quotidien/2:Boost/3:Invités/0:Vacances/255:Ignorer/4:MaxSpeed(DK)"
 |  | 258 | $102 | Demande Programmateur | 1 | uint | 0 | 0 | 0 | 4 | 1 |  |  | Oui | Enum = "1:Quotidien/2:Boost/3:Invités/0:Vacances/4:MaxSpeed(DK)" | Enum = "1:Quotidien/2:Boost/3:Invités/0:Vacances/4:MaxSpeed(DK)"
 |  | 259 | $103 | Mode Bypass | 1 | uint | 0 | N/A |  |  |  |  |  | Oui | Enum = "0:Manuel/1:Auto"
 |  | 261 | $105 | Type 0-10V AI0 | 1 | uint | 0 | 2 | 0 | 2 | 2 |  |  | Oui | Enum = "0:Co2 Aldes/2:Générique Proportionnel/1:PM 2.5 VOC China"
 |  | 262 | $106 | Type 0-10V AI1 | 1 | uint | 0 | 2 | 0 | 2 | 2 |  |  | Oui | Enum = "0:Co2 Aldes/2:Générique Proportionnel/1:PM 2.5 VOC China"
 |  | 267 | $10B | Tempo Filtre | 1 | uint | 0 | 0 | 3 | 12 | 6 | mois |  | Oui
 |  | 278 | $116 | UnbalanceCoefMVI | 1 | sint | 0 | 0 | 50 | 150 | 100 | % |  | Oui
 |  | 290 | $122 | unbalanceMode | 1 | uint | 0 | 2 |  |  |  |  |  | Oui | Enum = "0:SPL/1:Foyer ouvert"
 | Paramètres de Config France
 |  | 296 | $128 | Type Logement | 1 | sint | 0 | 2 | 2 | 6 | 2 |  |  | Oui
 |  | 297 | $129 | nb SDB | 1 | sint | 0 | 2 | 1 | 6 | 1 |  |  | Oui
 |  | 298 | $12A | nb WC | 1 | sint | 0 | 2 | 1 | 6 | 1 |  |  | Oui
 |  | 299 | $12B | nb Pièce Eau | 1 | sint | 0 | 2 | 1 | 6 | 1 |  |  | Oui
 | Commande Ventilateurs
 |  | 320 | $140 | ExhaustFanVoltage | 1 | uint | 3 | 3 | 0 | 10 |  | V | 0.001 | Oui
 |  | 321 | $141 | SupplyFanVoltage | 1 | uint | 3 | 3 | 0 | 10 |  | V | 0.001 | Oui
 | Pilotage BCA iBus
 |  | 323 | $143 | ConsignePreheater_BCAIBus | 1 | sint | 2 | 2 |  |  |  | °C | 0.01 | Oui
 | Pilotage Led RGB
 |  | 326 | $146 | LedRGBCurColor | 2 | uint | 0 | 2 |  |  |  |  |  | Oui
 | Switchs
 |  | 339 | $153 | GlobalBitsSwitch | 1 | uint | 0 | N/A |  |  |  |  |  | Oui
 | Etat du Filtre
 |  | 346 | $15A | EtatEncrassementFiltre | 1 | uint | 0 | N/A | 0 | 100 | 0 | % |  | Oui
 |  | 347 | $15B | TimerEncrassementFiltre | 1 | uint | 0 | 2 | 0 | 65535 | 0 | h |  | Oui
 | Bypass
 |  | 348 | $15C | BypassCurrentPosition | 1 | uint | 0 | N/A |  |  |  |  |  | Oui | Enum = "0:Indéfini/1:Ouvert/2:Fermé 45°c/3:Fermé"
 | Sondes T°
 |  | 350 | $15E | Ctn Entrée | 1 | sint | 0 | 4 |  |  |  | °C | 0.01 | Oui
 |  | 351 | $15F | Ctn Intérieur | 1 | sint | 0 | 4 |  |  |  | °C | 0.01 | Oui
 |  | 352 | $160 | Ctn Insufflation | 1 | sint | 3 | 4 |  |  |  | °C | 0.01 | Oui
 |  | 353 | $161 | Ctn Rejet | 1 | sint | 3 | 4 |  |  |  | °C | 0.01 | Oui
 | Retours Ventilateurs
 |  | 354 | $162 | SpeedExhaustFan | 1 | uint | 3 | N/A |  |  |  | RPM |  | Oui
 |  | 355 | $163 | SpeedSupplyFan | 1 | uint | 3 | N/A |  |  |  | RPM |  | Oui
 |  | 356 | $164 | Consigne Débit MVE | 1 | uint | 3 | N/A | 60 | 450 |  | m³/h |  | Oui
 |  | 357 | $165 | Consigne Débit MVI | 1 | uint | 3 | N/A | 60 | 450 |  | m³/h |  | Oui
 |  | 358 | $166 | Pression | 1 | sint | 3 | N/A |  |  |  | Pa | 0.1 | Oui
 | Détection Saison
 |  | 373 | $175 | Saison Détectée | 1 | uint | 2 | N/A | 0 | 2 | 0 |  |  | Oui | Enum = "0:Inconnu/1:Hiver/2:Eté"
 | Capteurs T° & HR
 |  | 378 | $17A | HR_1 | 1 | sint | 0 | N/A | 0 | 100 |  | % | 0.1 | Oui
 |  | 379 | $17B | T°_1 | 1 | sint | 0 | N/A |  |  |  | °c | 0.1 | Oui
 |  | 380 | $17C | HR_Aux | 1 | sint | 0 | N/A | 0 | 100 |  | % | 0.1 | Oui
 |  | 381 | $17D | T°_Aux | 1 | sint | 0 | N/A |  |  |  | °c | 0.1 | Oui
 | Codes Erreur
 |  | 384 | $180 | ErrorCode | 1 | uint | 0 | N/A |  |  |  |  |  | Oui | Enum = "0:NoError/49:NoProductId/50:NoMiseEnService/53:Défaut Capteur Pression/70:Contact Sec Actif/72:Défaut Sonde HR/76:Défaut Sonde Co2 IHM/81:BCA Absente/82:Echec BCA/83:Défaut BCA PréChauf. Ext./84:Défaut PréChauffage Int./85:Défaut BCA PostChauf. Ext./90:Echec Test FireDamper/91:FireDamper Fermé/182:Défaillance MVE/183:Défaillance MVI/239:Défaut sonde Rejet/240:Défaut sonde Extérieur/241:Défaut sonde Insufflation/251:Défaut Sonde VMC"
 | Capteur de Pression
 |  | 415 | $19F | Capture_Offset | 1 | uint | 3 | 3 |  |  |  |  |  | Oui | Enum = "0:Idle/256:Capture/512:Sauvegarder/768:Capt & Save/1:Terminé/513:Ended & onSave/514:Sauvegardé/515:Done & Saved"
 |  | 416 | $1A0 | I2cPressureDeviceType | 1 | uint | 0 | N/A |  |  |  |  |  | Oui | Enum = "0:NotAvailable/1:HONEYWELL_28/2:HONEYWELL_38/32769:Try HONEYWELL_28/32770:Try HONEYWELL_38"
 |  | 420 | $1A4 | Pressure_Offset | 1 | uint | 0 | 2 |  |  |  |  |  | Oui
 | Capteurs sur IHM
 |  | 448 | $1C0 | HR IHM | 1 | uint | 2 | 3 | 0 | 100 |  | % | 0.1 | Oui
 |  | 449 | $1C1 | T° IHM | 1 | sint | 2 | 3 |  |  |  | °C | 0.01 | Oui
 |  | 450 | $1C2 | Co2 IHM | 1 | uint | 2 | 3 |  |  |  | ppm Co2 |  | Oui
 | Infos IOT
 |  | 464 | $1D0 | Override | 1 | uint | 2 | 2 |  |  |  |  |  | Oui | Enum = "0:Désactivé/1:Activé"
 | Paramètres Affichage
 |  | 480 | $1E0 | Langue Affichage | 1 | uint | 0 | 2 | 1 | 7 | 1 |  |  | Oui | Enum = "1:Français/2:Anglais/3:Allemand/4:Espagnol/5:Italien/6:Néerlandais/7:Danois/0:Inconnu"
 |  | 481 | $1E1 | Animation Led | 1 | uint | 0 | 2 | 0 | 2 | 0 |  |  | Oui | Enum = "0:QAI/1:Battements/2:Désactivée"
 |  | 482 | $1E2 | Unité Débits | 1 | uint | 0 | 2 | 1 | 3 | 1 |  |  | Oui | Enum = "1:m3_h/2:L_s/3:CFM"
 |  | 483 | $1E3 | Unité Pression | 1 | uint | 0 | 2 | 1 | 2 | 1 |  |  | Oui | Enum = "1:Pa/2:Po.H2O"
 |  | 484 | $1E4 | Unité Vitesse | 1 | uint | 0 | 2 | 1 | 2 | 1 |  |  | Oui | Enum = "1:RPM/2:en %"
 |  | 485 | $1E5 | Unité Température | 1 | uint | 0 | 2 | 1 | 2 | 1 |  |  | Oui | Enum = "1:°C/2:°F"
 | Paramètres Divers
 |  | 486 | $1E6 | T° Confort Post-Chauffe | 1 | sint | 0 | 2 | 19 | 28 | 27 | °C | 0.01 | Oui
 |  | 487 | $1E7 | Pays | 1 | uint | 0 | 2 |  |  | 0 |  |  | Oui | Enum = "1:France/2:Angleterre/3:Allemagne/4:Espagne/5:Italie/6:Benelux/7:Danemark/10:Nord-Amérique/15:Chine/0:Inconnu"
 |  | 488 | $1E8 | UserUsbBehaviour | 1 | uint | 0 | 0 | 0 | 2 | 2 |  |  | Oui | Enum = "0:None/1:Host/2:Device/-1:AutoDetectNow/65535:AutoDetectNow"
 |  | 490 | $1EA | TypeFiltreInsufflation | 1 | uint | 0 | 2 | 1 | 6 | 0 |  |  | Oui | Enum = "1:Poussière/2:Pollen/3:Particules/4:Particules fines/5:Bactéries/6:COV/0:Inconnu"
 |  | 491 | $1EB | TypeFiltreExtraction | 1 | uint | 0 | 2 | 1 | 6 | 0 |  |  | Oui | Enum = "1:Poussière/2:Pollen/3:Particules/4:Particules fines/5:Bactéries/6:COV/0:Inconnu"
 |  | 492 | $1EC | T° Bypass Eté | 1 | sint | 0 | 2 | 19 | 28 | 27 | °C | 0.01 | Oui
 |  | 493 | $1ED | Mode Radon | 1 | uint | 0 | 2 |  |  |  |  |  | Oui | Enum = "0:Inactif/1:Actif"
 | Bypass motor Cmd
 |  | 768 | $300 | BypassFullOpenOrClose | 1 | uint | N/A | 4 | 0 | 2 | 0 |  |  | Oui | Enum = "0:Idle/1:FullOpen/2:FullClose"
 |  | 769 | $301 | BypassOpenAngle | 1 | uint | N/A | 4 |  |  |  | deg |  | Oui
 |  | 770 | $302 | BypassCloseAngle | 1 | uint | N/A | 4 |  |  |  | deg |  | Oui
 |  | 771 | $303 | ReductionCoefficientSTEPPER_ST_35 | 1 | uint | 0 | 2 |  |  |  |  |  | Oui
 | Fire Damper
 |  | 895 | $37F | FireDamperSoftVersion | 1 | uint | 0 | N/A |  |  |  |  |  | Oui
 |  | 896 | $380 | StepFireDamper | 1 | uint | 0 | 3 |  |  |  |  |  | Oui | Enum = "0:Idle/32769:StartTest/1:Préavis coupure/2:Starting Close/3:Waiting Close/4:Starting Open/5:Waiting Open/6:Log Result"
 |  | 897 | $381 | FireDamper1LastTestResult | 1 | uint | 0 | N/A |  |  |  |  |  | Oui | Enum = "0:Non Testé/1:Défaut Fermeture/2:Défaut Ouverture/3:Défauts Ouv&Ferm./4:Test Réussi"
 |  | 898 | $382 | FireDamper2LastTestResult | 1 | uint | 0 | N/A |  |  |  |  |  | Oui | Enum = "0:Non Testé/1:Défaut Fermeture/2:Défaut Ouverture/3:Défauts Ouv&Ferm./4:Test Réussi"
 |  | 899 | $383 | FireDamperLastTestRequester | 1 | uint | 0 | N/A |  |  |  |  |  | Oui | Enum = "0:Inconnu/1:Automatique/2:Manuel"
 |  | 900 | $384 | FireDamperLastTestDate32 | 2 | uint | 0 | N/A |  |  |  |  |  | Oui
 |  | 904 | $388 | NbFireDampers | 1 | uint | 0 | 2 | 0 | 2 | 0 |  |  | Oui
 |  | 905 | $389 | NbDaysFireDamper | 1 | uint | 0 | 2 | 0 | 65535 | 7 | jours |  | Oui
 |  | 906 | $38A | FireDamperAutoTestWeekDay | 1 | uint | 0 | 2 | 0 | 6 | 0 |  |  | Oui | Enum = "0:Lundi/1:Mardi/2:Mercredi/3:Jeudi/4:Vendredi/5:Samedi/6:Dimanche"
 |  | 907 | $38B | FireDamperAutoTestHour | 1 | uint | 0 | 2 | 0 | 23 | 12 | h |  | Oui
 |  | 908 | $38C | FireDamperAutoTestMinut | 1 | uint | 0 | 2 | 0 | 59 | 0 | min. |  | Oui
 |  | 909 | $38D | CptNbDaysWithoutFireDamper | 1 | uint | 0 | 2 | 0 | 65535 | 0 | jours |  | Oui
 |  | 910 | $38E | FireDamper1Status | 1 | uint | 0 | N/A |  |  |  |  |  | Oui | Enum = "0:Fermé/90:Ouvert/254:Indéterminé/255:Pas de Réponse/510:Déconnecté/511:Absent"
 |  | 911 | $38F | FireDamper2Status | 1 | uint | 0 | N/A |  |  |  |  |  | Oui | Enum = "0:Fermé/90:Ouvert/254:Indéterminé/255:Pas de Réponse/510:Déconnecté/511:Absent"
 | Fans motor Cmd
 |  | 1024 | $400 | ExhaustFanVoltage | 1 | uint | 3 | 4 | 0 | 10 |  | V | 0.001 | Oui
 |  | 1025 | $401 | SupplyFanVoltage | 1 | uint | 3 | 4 | 0 | 10 |  | V | 0.001 | Oui
 |  | 1026 | $402 | SpeedExhaustFan | 1 | uint | 3 | N/A |  |  |  | RPM |  | Oui
 |  | 1027 | $403 | SpeedSupplyFan | 1 | uint | 3 | N/A |  |  |  | RPM |  | Oui
 |  | 1028 | $404 | FanConfig | 1 | uint | 0 | 2 | 1 | 2 | 0 |  |  | Oui | Enum = "2:Config A/1:Config B/0:None"
 | Consignes par Niveau
 |  | 1040 | $410 | Consigne MVE Absent | 1 | uint | 0 | 2 |  |  |  |  |  | Oui
 |  | 1041 | $411 | Consigne MVI Absent | 1 | uint | 0 | 2 |  |  |  |  |  | Oui
 |  | 1042 | $412 | Consigne MVE Quotidien | 1 | uint | 0 | 2 |  |  |  |  |  | Oui
 |  | 1043 | $413 | Consigne MVI Quotidien | 1 | uint | 0 | 2 |  |  |  |  |  | Oui
 |  | 1044 | $414 | Consigne MVE Boost | 1 | uint | 0 | 2 |  |  |  |  |  | Oui
 |  | 1045 | $415 | Consigne MVI Boost | 1 | uint | 0 | 2 |  |  |  |  |  | Oui
 |  | 1046 | $416 | Consigne MVE Invités | 1 | uint | 0 | 2 |  |  |  |  |  | Oui
 |  | 1047 | $417 | Consigne MVI Invités | 1 | uint | 0 | 2 |  |  |  |  |  | Oui
 |  | 1048 | $418 | Consigne MVE MaxSpeed | 1 | uint | 0 | 2 |  |  |  |  |  | Oui
 |  | 1049 | $419 | Consigne MVI MaxSpeed | 1 | uint | 0 | 2 |  |  |  |  |  | Oui
 | Sortie de Régulation
 |  | 1056 | $420 | Niveau Actuel | 1 | uint | 0 | N/A | 0 | 4 | 1 |  |  | Oui | Enum = "1:Quotidien/2:Boost/3:Invités/0:Vacances/4:MaxSpeed(DK)"
 |  | 1057 | $421 | Demandeur | 1 | uint | 0 | N/A |  |  |  |  |  | Oui | Enum = "0:User/1:Prog IOT/2:Capteur IOT/3:Régulation/4:Option HR/5:Entrée AI0/6:Entrée AI1/7:Bouton Cuisine/8:Co2 IHM/9:Mode SAFE/10:Air Prog"
 | FineTune par Niveau
 |  | 1074 | $432 | FineTune MVE Quotidien | 1 | uint | 0 | 2 |  |  |  |  |  | Oui
 |  | 1075 | $433 | FineTune MVI Quotidien | 1 | uint | 0 | 2 |  |  |  |  |  | Oui
 |  | 1076 | $434 | FineTune MVE Boost | 1 | uint | 0 | 2 |  |  |  |  |  | Oui
 |  | 1077 | $435 | FineTune MVI Boost | 1 | uint | 0 | 2 |  |  |  |  |  | Oui
 | Capteur de Pression I2C
 |  | 1296 | $510 | Pression | 1 | sint | 3 | N/A |  |  |  | Pa | 0.1 | Oui
 |  | 1297 | $511 | T° CptPres | 1 | sint | 3 | N/A |  |  |  | °c | 0.1 | Oui
 |  | 1298 | $512 | Pressure_Offset | 1 | uint | 0 | 2 |  |  |  |  |  | Oui
 | DateTime RTC
 |  | 1302 | $516 | DateTime32 | 2 | uint | 0 | 2 |  |  |  | s |  | Oui
 |  | 1304 | $518 | Date_Year | 1 | uint | 0 | 2 | 2020 |  |  |  |  | Oui
 |  | 1305 | $519 | Date_Month | 1 | uint | 0 | 2 | 1 | 12 | 1 |  |  | Oui | Enum = "1:Janvier/2:Février/3:Mars/4:Avril/5:Mai/6:Juin/7:Juillet/8:Août/9:Septembre/10:Octobre/11:Novembre/12:Décembre"
 |  | 1306 | $51A | Date_Day | 1 | uint | 0 | 2 | 1 | 31 | 1 |  |  | Oui
 |  | 1307 | $51B | Date_WeekDay | 1 | uint | 0 | 2 | 0 | 6 | 0 |  |  | Oui | Enum = "0:Lundi/1:Mardi/2:Mercredi/3:Jeudi/4:Vendredi/5:Samedi/6:Dimanche"
 |  | 1308 | $51C | Time_Hours | 1 | uint | 0 | 2 | 0 | 23 | 0 | h |  | Oui
 |  | 1309 | $51D | Time_Minuts | 1 | uint | 0 | 2 | 0 | 59 | 0 | m |  | Oui
 |  | 1310 | $51E | Time_Seconds | 1 | uint | 0 | 2 | 0 | 59 | 0 | s |  | Oui
 | I2C Detected Devices
 |  | 1344 | $540 | I2cPressureDeviceType | 1 | uint | 0 | N/A |  |  |  |  |  | Oui | Enum = "0:NotAvailable/1:HONEYWELL_28/2:HONEYWELL_38/32769:Try HONEYWELL_28/32770:Try HONEYWELL_38"
 |  | 1345 | $541 | I2cRtcDeviceType | 1 | uint | 0 | N/A |  |  |  |  |  | Oui | Enum = "0:NotAvailable/1:MC_RV_3028/32769:Try MC_RV_3028"
 |  | 1346 | $542 | I2cHr1DeviceType | 1 | uint | 0 | N/A |  |  |  |  |  | Oui | Enum = "0:NotAvailable/1:SHT_30_A/2:SHT_30_B/32769:Try SHT_30_A/32770:Try SHT_30_B"
 |  | 1347 | $543 | I2cHrAuxDeviceType | 1 | uint | 0 | N/A |  |  |  |  |  | Oui | Enum = "0:NotAvailable/1:SHT_30_A/2:SHT_30_B/32769:Try SHT_30_A/32770:Try SHT_30_B"
 |  | 1348 | $544 | I2cInternalResetPin | 1 | uint | N/A | 4 |  |  |  |  |  | Oui | Enum = "0:No Change/32768:Force Reset/32769:Force Normal"
 |  | 1349 | $545 | I2cExternalResetPin | 1 | uint | N/A | 4 |  |  |  |  |  | Oui | Enum = "0:No Change/32768:Force Reset/32769:Force Normal"
 | Mémoire Externe
 |  | 1408 | $580 | MemoryJedecID | 2 | uint | 0 | N/A |  |  |  |  |  | Oui | Enum = "1450178:MX25L3233F/1466525:IS25LP032"
 |  | 1410 | $582 | MemoryCompatType | 1 | uint | 0 | N/A |  |  |  |  |  | Oui | Enum = "0:Inconnu/1:SST25/2:SST26/3:MX25L/4:IS25LP"
 | USB
 |  | 1424 | $590 | CurUsbBehaviour | 1 | uint | 0 | N/A |  |  |  |  |  | Oui | Enum = "0:None/1:Host/2:Device/-1:AutoDetectNow/65535:AutoDetectNow"
 |  | 1425 | $591 | curUsbBehaviourStep | 1 | uint | 0 | N/A |  |  |  |  |  | Oui | Enum = "0:NotInit/1:InitHost/2:RunHost/3:DeInitHost/4:InitDevice/5:RunDevice/6:DeInitDevice/7:InitNone/8:RunNone"
 |  | 1426 | $592 | sabUsbBehaviour | 2 | sint | 0 | N/A |  |  |  | s | 0.1 | Oui
 |  | 1428 | $594 | UserUsbBehaviour | 1 | uint | 0 | 0 | 0 | 2 | 2 |  |  | Oui | Enum = "0:None/1:Host/2:Device/-1:AutoDetectNow/65535:AutoDetectNow"
 |  | 1429 | $595 | UsbMscStatus | 1 | uint | 0 | N/A |  |  |  |  |  | Oui | Enum = "0:Idle/1:Detected/2:Sel_Config/3:Cls_Selected/4:Ready/128:Error"
 |  | 1430 | $596 | UsbCdcStatus | 1 | uint | 0 | N/A |  |  |  |  |  | Oui | Enum = "0:Idle/1:Detected/2:Sel_Config/3:Cls_Selected/4:Ready/128:Error"
 | ADC values
 |  | 1568 | $620 | Alim 24V | 1 | uint | 0 | 3 |  |  |  | V | 0.001 | Oui
 |  | 1569 | $621 | Ctn Intérieur | 1 | sint | 0 | 3 |  |  |  | °C | 0.01 | Oui
 |  | 1570 | $622 | Ctn Entrée | 1 | sint | 0 | 3 |  |  |  | °C | 0.01 | Oui
 |  | 1571 | $623 | Ctn Insufflation | 1 | sint | 3 | 3 |  |  |  | °C | 0.01 | Oui
 |  | 1572 | $624 | Ctn BCA Pré-ch. | 1 | sint | 0 | 3 |  |  |  | °C | 0.01 | Oui
 |  | 1573 | $625 | Ctn BCA Post-ch. | 1 | sint | 0 | 3 |  |  |  | °C | 0.01 | Oui
 |  | 1574 | $626 | Ctn Rejet | 1 | sint | 3 | 3 |  |  |  | °C | 0.01 | Oui
 |  | 1575 | $627 | Entrée AI0 | 1 | uint | 0 | 3 |  |  |  | V | 0.001 | Oui
 |  | 1576 | $628 | Entrée AI1 | 1 | uint | 0 | 3 |  |  |  | V | 0.001 | Oui
 | BCA Interne et Externe
 |  | 1616 | $650 | ConsignePreheater | 1 | uint | 0 | 2 | 0 | 60 | 0 | s |  | Oui
 |  | 1617 | $651 | ConsignePostheater | 1 | uint | 0 | 2 | 0 | 60 | 0 | s |  | Oui
 |  | 1632 | $660 | BcaExpected | 1 | uint | 0 | 2 |  |  |  |  |  | Oui | Enum = "1:BCA Pré-Chauffe Ext/2:BCA Post-Chauffe Ext/0:Aucune/3:BCA Ext x2/8:BCA Pré-Chauffe Int/10:BCA Pré-Chauffe Int + BCA Post-Chauffe Ext"
 |  | 1633 | $661 | BcaPresent | 1 | uint | 0 | N/A |  |  |  |  |  | Oui | Enum = "1:BCA Pré-Chauffe Ext/2:BCA Post-Chauffe Ext/0:Aucune/3:BCA Ext x2"
 | Paramètres AI0 & AI1
 |  | 1664 | $680 | Tension Min AI0 | 1 | uint | 0 | 2 |  |  |  | V | 0.001 | Oui
 |  | 1665 | $681 | Niveau Min AI0 | 1 | uint | 0 | 2 | 0 | 1 | 1 |  |  | Oui | Enum = "1:Quotidien/0:Vacances"
 |  | 1666 | $682 | Consigne Min MVE AI0 | 1 | uint | 0 | N/A |  |  |  |  |  | Oui
 |  | 1667 | $683 | Consigne Min MVI AI0 | 1 | uint | 0 | N/A |  |  |  |  |  | Oui
 |  | 1676 | $68C | Tension Max AI0 | 1 | uint | 0 | 2 |  |  |  | V | 0.001 | Oui
 |  | 1677 | $68D | Niveau Max AI0 | 1 | uint | 0 | 2 | 2 | 3 | 2 |  |  | Oui | Enum = "2:Boost/3:Invités"
 |  | 1678 | $68E | Consigne Max MVE AI0 | 1 | uint | 0 | N/A |  |  |  |  |  | Oui
 |  | 1679 | $68F | Consigne Max MVI AI0 | 1 | uint | 0 | N/A |  |  |  |  |  | Oui
 |  | 1680 | $690 | Tension Min AI1 | 1 | uint | 0 | 2 |  |  |  | V | 0.001 | Oui
 |  | 1681 | $691 | Niveau Min AI1 | 1 | uint | 0 | 2 | 0 | 1 | 1 |  |  | Oui | Enum = "1:Quotidien/0:Vacances"
 |  | 1682 | $692 | Consigne Min MVE AI1 | 1 | uint | 0 | N/A |  |  |  |  |  | Oui
 |  | 1683 | $693 | Consigne Min MVI AI1 | 1 | uint | 0 | N/A |  |  |  |  |  | Oui
 |  | 1692 | $69C | Tension Max AI1 | 1 | uint | 0 | 2 |  |  |  | V | 0.001 | Oui
 |  | 1693 | $69D | Niveau Max AI1 | 1 | uint | 0 | 2 | 2 | 3 | 2 |  |  | Oui | Enum = "2:Boost/3:Invités"
 |  | 1694 | $69E | Consigne Max MVE AI1 | 1 | uint | 0 | N/A |  |  |  |  |  | Oui
 |  | 1695 | $69F | Consigne Max MVI AI1 | 1 | uint | 0 | N/A |  |  |  |  |  | Oui
 | Simulation & BDT
 |  | 2305 | $901 | BancDeTest | 1 | uint | 0 | 0 |  |  |  |  |  | Oui | Enum = "0:Non/1:Actif"
 | HR
 |  | 4432 | $1150 | ManualValueHR | 1 | sint | 0 | 0 |  |  |  |  | 0.1 | Oui
 |  | 4433 | $1151 | ConsigneHR | 1 | uint | 0 | 0 |  |  |  |  |  | Oui | Enum = "0:NORMALE/1:BOOST"
 |  | 4434 | $1152 | HRMoy5 | 1 | sint | 0 | 0 |  |  |  |  | 0.1 | Oui
 |  | 4435 | $1153 | HRVar5 | 1 | sint | 0 | 0 |  |  |  |  | 0.1 | Oui
 |  | 4436 | $1154 | HRMoy15 | 1 | sint | 0 | 0 |  |  |  |  | 0.1 | Oui
 |  | 4437 | $1155 | CounterBoostActif | 1 | uint | 0 | 0 |  |  |  |  |  | Oui
 |  | 4438 | $1156 | ValMVE_Boost | 1 | uint | 0 | 2 |  |  |  |  |  | Oui
 |  | 4439 | $1157 | ValMVI_Boost | 1 | uint | 0 | 2 |  |  |  |  |  | Oui
 | Push Button
 |  | 4693 | $1255 | CurrentPushButtonPressed | 1 | uint | 0 | N/A |  |  |  |  |  | Oui | Enum = "0:NotPressed/1:Pressed"
 | Gestion degivrage
 |  | 5120 | $1400 | Certification | 1 | uint | 0 | 0 |  |  |  |  |  | Oui | Enum = "0:Passiv'Haus/1:DIBT"
 |  | 5121 | $1401 | GestionDegivrageTsd | 1 | uint | 0 | 0 |  |  |  |  |  | Oui
 |  | 5122 | $1402 | TimeGestionDegivrage30min | 1 | uint | 0 | 0 |  |  |  | min |  | Oui
 |  | 5123 | $1403 | Temp_Exterieur_Limit_Moy | 1 | sint | 0 | 0 |  |  |  | °c | 0.01 | Oui
 |  | 5124 | $1404 | Temp_Exterieur_Seuil | 1 | sint | 0 | 0 |  |  |  | °c | 0.01 | Oui
 |  | 5125 | $1405 | Temp_Rejet_Seuil_Haut | 1 | sint | 0 | 0 |  |  |  | °c | 0.01 | Oui
 |  | 5126 | $1406 | Temp_Rejet_Seuil_Bas | 1 | sint | 0 | 0 |  |  |  | °c | 0.01 | Oui
 |  | 5127 | $1407 | GestionDegivrageHystPreheater | 1 | uint | 0 | 0 |  |  |  |  |  | Oui | Enum = "0:Repos/1:Activé"
 |  | 5128 | $1408 | GestionDegivrageErreurPreheater | 1 | sint | 0 | 0 |  |  |  |  |  | Oui
 |  | 5129 | $1409 | GestionDegivrageSommeErreurPreheater | 1 | sint | 0 | 0 |  |  |  |  |  | Oui
 |  | 5130 | $140A | GestionDegivrageKpPreheater | 1 | uint | 0 | 0 |  |  |  |  |  | Oui
 |  | 5131 | $140B | GestionDegivrageKiPreheater | 1 | uint | 0 | 0 |  |  |  |  |  | Oui
 |  | 5132 | $140C | GestionDegivrageConsignePreheater | 1 | sint | 0 | 0 |  |  |  |  |  | Oui
 |  | 5133 | $140D | GestionDegivrageSablierDegivrage | 1 | uint | 0 | N/A |  |  |  |  |  | Oui
 |  | 5134 | $140E | ConsignePreheater_BCAIBus | 1 | sint | 0 | 0 |  |  |  | °C | 0.01 | Oui
 | Output PWM
 |  | 5376 | $1500 | OutputPwmValue | 1 | uint | 0 | 4 | 0 | 10 | 0 | V | 0.01 | Oui
 | Gestion contact sec
 |  | 12370 | $3052 | EtatContactSec | 1 | uint | 0 | N/A | 0 | 1 | 0 |  |  | Oui | Enum = "0:Contact Open/1:Contact Close"
 |  | 12371 | $3053 | ModeContactSec | 1 | uint | 0 | 2 | 0 | 1 | 0 |  |  | Oui | Enum = "0:Normaly Open/1:Normaly Close"
 |  | 12372 | $3054 | StatutContactSec | 1 | uint | 0 | N/A | 0 | 1 | 0 |  |  | Oui | Enum = "0:Normal Position/1:Working Position"
 |  | 40020 | $9C54 | InstallCodePin | 1 | uint | 3 | N/A |  |  |  |  |  | Oui
 | BootLoader Infos
 |  | 65280 | $FF00 | BlVersionInfo | 1 | uint | 0 | N/A |  |  |  |  |  | Oui
 |  | 65281 | $FF01 | FW_RunTime | 2 | uint | 0 | N/A |  |  |  | s |  | Oui
 |  | 65283 | $FF03 | FW_RunMode | 1 | uint | 0 | 0 | 1 | 2 | 2 |  |  | Oui | Enum = "1:BootLoader/2:Applicatif"
 |  | 65284 | $FF04 | FW_RunStatus | 1 | uint | 0 | N/A |  |  |  |  |  | Oui | Enum = "1:Ready 4 Cmd/2:Update Pending/257:Ready 4 App/513:On Jump 2 BL"
 |  | 65285 | $FF05 | sabJumpToBL | 1 | uint | 0 | N/A |  |  |  | s | 0.1 | Oui
 |  | 65286 | $FF06 | BL_Requesters | 1 | uint | 0 | N/A |  |  |  |  |  | Oui | Enum = "0:None/1:System/2:IHM/4:User/8:USB"
 | Infos ST
 |  | 65344 | $FF40 | UID_0 | 2 | uint | 0 | N/A |  |  |  |  |  | Oui
 |  | 65346 | $FF42 | UID_1 | 2 | uint | 0 | N/A |  |  |  |  |  | Oui
 |  | 65348 | $FF44 | UID_2 | 2 | uint | 0 | N/A |  |  |  |  |  | Oui
 |  | 65350 | $FF46 | UID_3 | 2 | uint | 0 | N/A |  |  |  |  |  | Oui
 |  | 65352 | $FF48 | FlashSize | 1 | uint | 0 | N/A |  |  |  | KB Flash |  | Oui
 |  | 65353 | $FF49 | PackageSize_0 | 1 | uint | 0 | N/A |  |  |  |  |  | Oui
 |  | 65354 | $FF4A | PackageSize_1 | 1 | uint | 0 | N/A |  |  |  |  |  | Oui
 |  | 65355 | $FF4B | PackageSize_2 | 1 | uint | 0 | N/A |  |  |  |  |  | Oui
 |  | 65356 | $FF4C | PackageSize_3 | 1 | uint | 0 | N/A |  |  |  |  |  | Oui
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

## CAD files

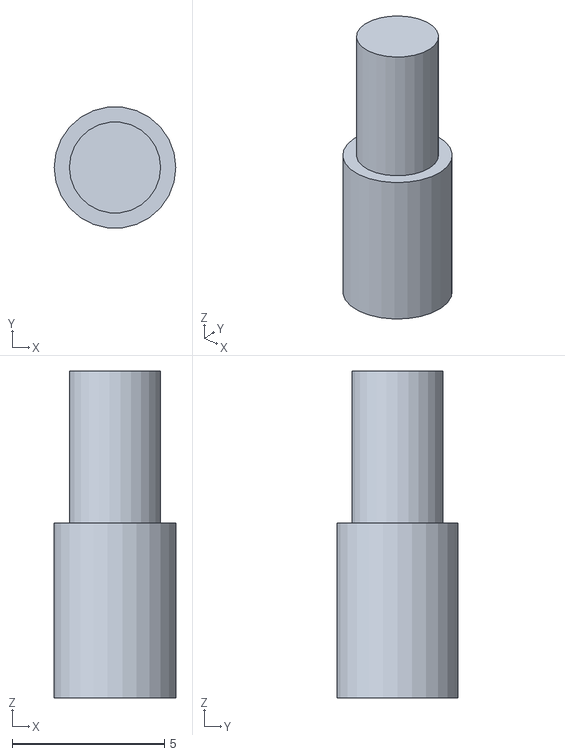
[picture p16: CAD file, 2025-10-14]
3Dprint/STL/zMod_enclosure-Button.stl
4.00 x 3.97 x 10.8

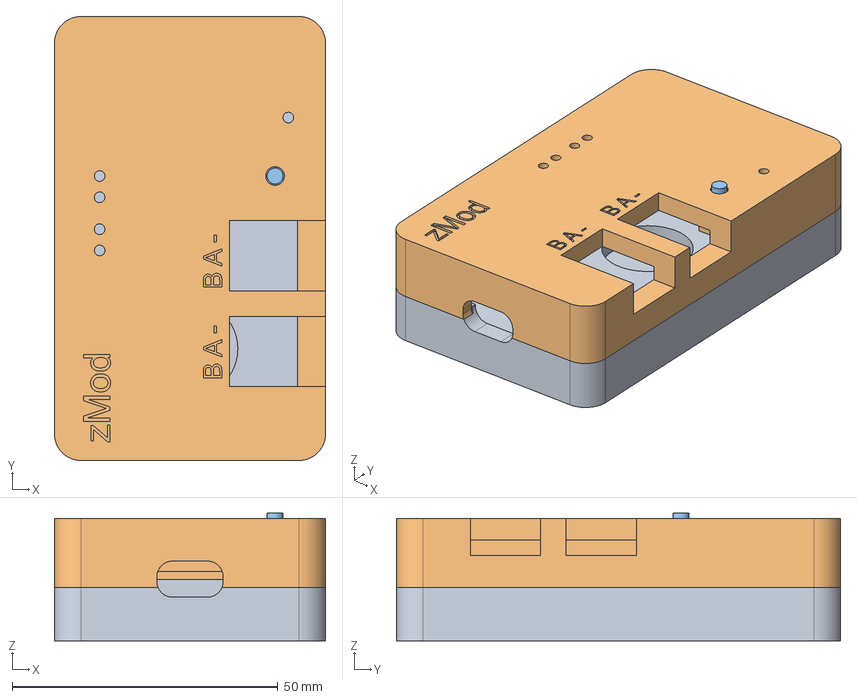
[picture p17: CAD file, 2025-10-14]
3Dprint/zMod_enclosure.FCStd
51.0 x 83.5 x 24.0 mm
Enclosure_bottom
Enclosure_Top
Button

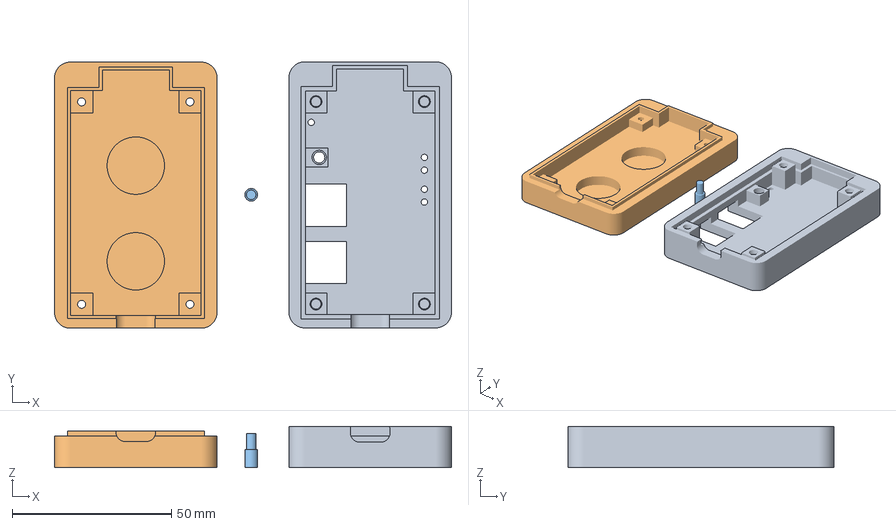
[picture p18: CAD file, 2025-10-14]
3Dprint/STL/zMod_enclosure-Enclosure_Top.3mf
124.5 x 83.6 x 13.0 mm
zMod_enclosure-Enclosure_Top.stl
zMod_enclosure-Enclosure_bottom.stl
zMod_enclosure-Button.stl

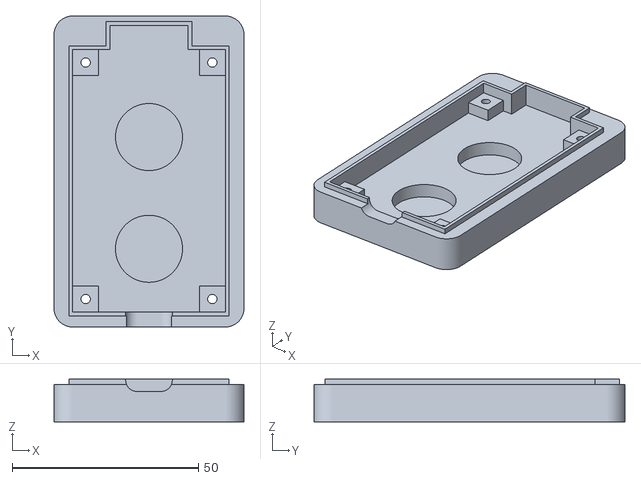
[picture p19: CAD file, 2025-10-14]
3Dprint/STL/zMod_enclosure-Enclosure_bottom.stl
51.0 x 83.5 x 11.5

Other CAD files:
3Dprint/STL/zMod_enclosure-Enclosure_Top.stl

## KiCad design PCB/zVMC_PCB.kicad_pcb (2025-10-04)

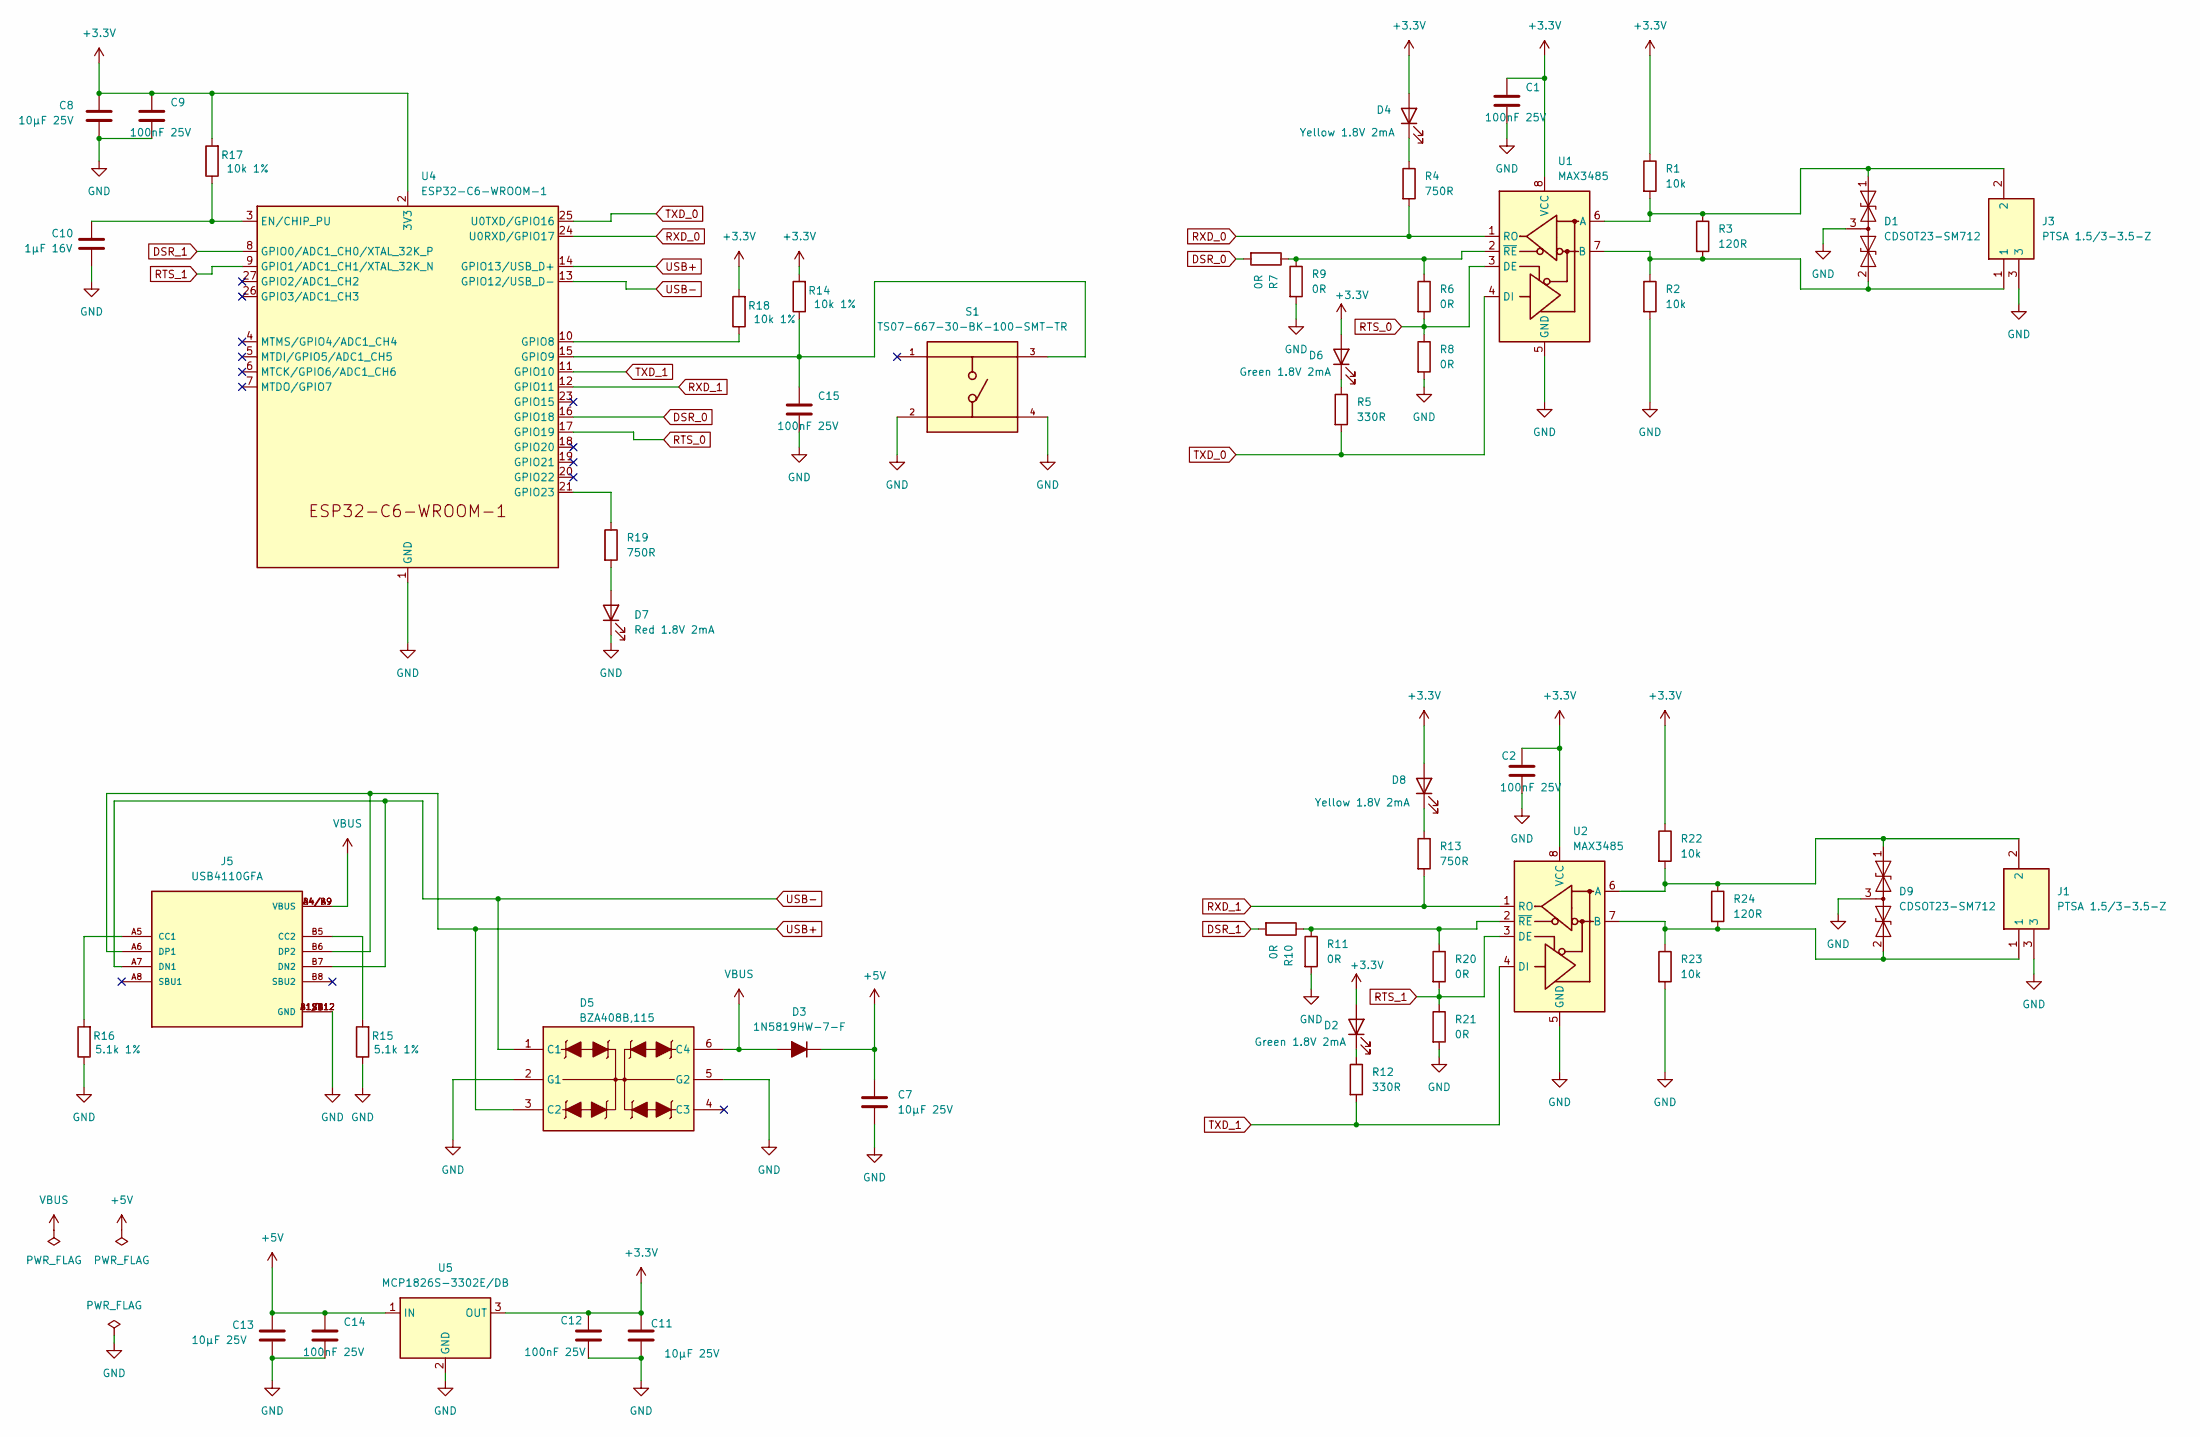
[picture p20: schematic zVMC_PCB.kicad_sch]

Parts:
C1, C2, C9, C12, C14, C15: 100nF 25V; C_0805_2012Metric
C7, C8, C11, C13: 10µF 25V; C_0805_2012Metric
C10: 1µF 16V; C_0805_2012Metric
D1, D9: CDSOT23-SM712; SOT-23
D2, D6: Green 1.8V 2mA; D_0805_2012Metric
D3: 1N5819HW-7-F; D_SOD-123
D4, D8: Yellow 1.8V 2mA; D_0805_2012Metric_Pad1.15x1.40mm_HandSolder
D5: BZA408B,115; SOT95P275X110-6N; Mouser Part Number 771-BZA408B,125
D7: Red 1.8V 2mA; D_0805_2012Metric
J1, J3: PTSA 1.5/3-3.5-Z; Phoenix Contact PTSA 3; Mouser Part Number 651-1985205
J5: USB4110GFA; GCT_USB4110GFA
R1, R2, R22, R23: 10k; R_0805_2012Metric
R3, R24: 120R; R_0805_2012Metric
R4, R13, R19: 750R; R_0805_2012Metric
R5, R12: 330R; R_0805_2012Metric
R6, R7, R8, R9, R10, R11, R20, R21: 0R; R_0805_2012Metric
R14, R17, R18: 10k 1%; R_0805_2012Metric
R15, R16: 5.1k 1%; R_0805_2012Metric
S1: TS07-667-30-BK-100-SMT-TR; CUI switch SW_TS07-667-30-BK-100-SMT-TR; PARTREV 1.0
U1, U2: MAX3485; SOIC-8_3.9x4.9mm_P1.27mm
U4: ESP32-C6-WROOM-1
U5: MCP1826S-3302E/DB; SOT-223-3_TabPin2

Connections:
+3.3V: C1.1, C2.1, C8.1, C9.1, C11.1, C12.1, D2.2 (A), D4.2 (A), D6.2 (A), D8.2 (A), R1.1, R14.2, R17.2, R18.2, R22.1, U1.8 (VCC), U2.8 (VCC), U4.2 (3V3), U5.3 (OUT)
+5V: C7.1, C13.1, C14.1, D3.1 (K), U5.1 (IN)
DSR_0: R7.2, U4.16 (GPIO18)
DSR_1: R10.2, U4.8 (GPIO0/ADC1_CH0/XTAL_32K_P)
GND: C1.2, C2.2, C7.2, C8.2, C9.2, C10.2, C11.2, C12.2, C13.2, C14.2, C15.2, D1.3 (common), D5.2 (G1), D5.5 (G2), D7.1 (K), D9.3 (common), J1.3, J3.3, J5.A1/B12 (GND), J5.B1/A12 (GND), J5.S1 (GND), J5.S2 (GND), J5.S3 (GND), J5.S4 (GND), R2.2, R8.2, R9.2, R11.2, R15.1, R16.1, R21.2, R23.2, S1.2, S1.4, U1.5 (GND), U2.5 (GND), U4.1 (GND), U4.28 (GND), U4.29 (GND), U5.2 (GND)
unnamed: D1.1 (A1), J3.2, R1.2, R3.1, U1.6 (A)
unnamed: D1.2 (A2), J3.1, R2.1, R3.2, U1.7 (B)
unnamed: D2.1 (K), R12.1
unnamed: D4.1 (K), R4.1
unnamed: D6.1 (K), R5.1
unnamed: D7.2 (A), R19.2
unnamed: D8.1 (K), R13.1
unnamed: D9.1 (A1), J1.2, R22.2, R24.1, U2.6 (A)
unnamed: D9.2 (A2), J1.1, R23.1, R24.2, U2.7 (B)
unnamed: J5.A5 (CC1), R16.2
unnamed: J5.B5 (CC2), R15.2
unnamed: R6.1, R7.1, R9.1, U1.2 (~RE)
unnamed: R10.1, R11.1, R20.1, U2.2 (~RE)
unnamed: C10.1, R17.1, U4.3 (EN/CHIP_PU)
unnamed: R18.1, U4.10 (GPIO8)
unnamed: C15.1, R14.1, S1.3, U4.15 (GPIO9)
unnamed: R19.1, U4.21 (GPIO23)
RTS_0: R6.2, R8.1, U1.3 (DE), U4.17 (GPIO19)
RTS_1: R20.2, R21.1, U2.3 (DE), U4.9 (GPIO1/ADC1_CH1/XTAL_32K_N)
RXD_0: R4.2, U1.1 (RO), U4.24 (U0RXD/GPIO17)
RXD_1: R13.2, U2.1 (RO), U4.12 (GPIO11)
TXD_0: R5.2, U1.4 (DI), U4.25 (U0TXD/GPIO16)
TXD_1: R12.2, U2.4 (DI), U4.11 (GPIO10)
USB+: D5.3 (C2), J5.A6 (DP1), J5.B6 (DP2), U4.14 (GPIO13/USB_D+)
USB-: D5.1 (C1), J5.A7 (DN1), J5.B7 (DN2), U4.13 (GPIO12/USB_D-)
VBUS: D3.2 (A), D5.6 (C4), J5.A4/B9 (VBUS), J5.B4/A9 (VBUS)

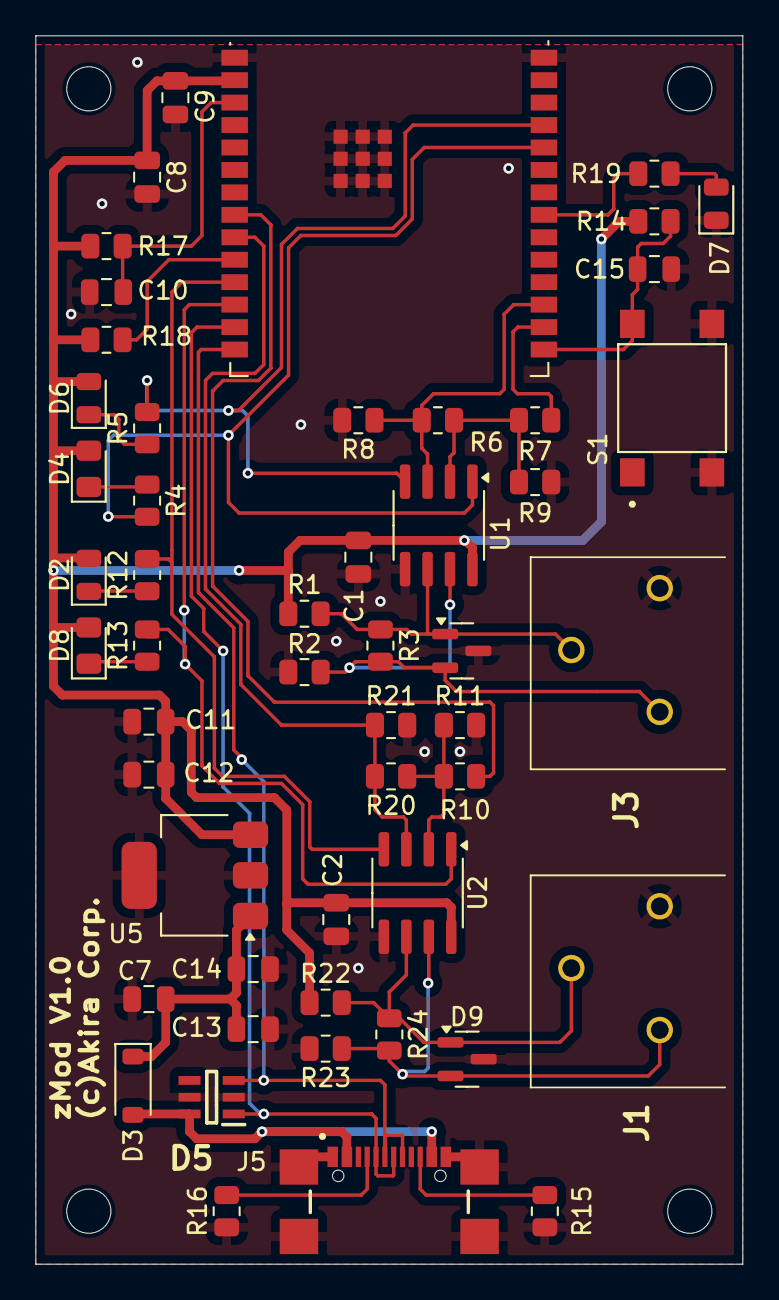
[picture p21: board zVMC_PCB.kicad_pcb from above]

Board: 2 copper layers, 40.0 x 69.5 mm, 52 parts (0 on the bottom side), 31 nets.

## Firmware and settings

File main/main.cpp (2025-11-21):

//#define LOG_LOCAL_LEVEL ESP_LOG_VERBOSE

#include "main.h"

#include <freertos/FreeRTOS.h>
#include <freertos/task.h>
#include <esp_log.h>
#include <functional>

#include <iostream>

#include <vector> // todel

#include "zbEndpoint.h" // to del
#include "periodicSoftTask.h" // to del

#include "zbEndpoint.h" // to del


#include "AldesModbus.h"

static const char *TAG = "Main_app";
BlinkTask* Main::_ledBlinking = nullptr;
GpioOutput Main::_led { (gpio_num_t)CONFIG_PIN_LED }; //TODO led pin number in config file

Main App;

Main::Main()
{
    // Setting the log level for each module
    esp_log_level_set("Main_app", ESP_LOG_DEBUG);  // Put verbose to check available stack
    esp_log_level_set("Modbus", ESP_LOG_INFO); 
    esp_log_level_set("AldesDriver", ESP_LOG_INFO);
    esp_log_level_set("ZbNode", ESP_LOG_INFO); 
    esp_log_level_set("ZbEndpoint", ESP_LOG_VERBOSE);
    esp_log_level_set("ZbCluster", ESP_LOG_INFO);
    esp_log_level_set("EventLoop", ESP_LOG_DEBUG);
    esp_log_level_set("PersistedValue", ESP_LOG_VERBOSE); 
}

// static
void Main::ledFlash(uint64_t speed)
{
    if(speed == 0) 
    {
        if(_ledBlinking){
        delete _ledBlinking;
        _ledBlinking = nullptr;
        }
        _led.off();
    } else if(speed == -1) {
        if(_ledBlinking){
        delete _ledBlinking;
        _ledBlinking = nullptr;
        }
        _led.on();
    } else {
        if(!_ledBlinking)
            _ledBlinking = new BlinkTask(_led, speed); // very short flash
        else
            _ledBlinking->setBlinkPeriod(speed);
    }

}

//Static
void Main::shortPressHandler(void *handler_args, esp_event_base_t base, int32_t id, void *event_data)
{
    ESP_LOGV(TAG,"Short Press detected %ld -",id);
    if(ZbNode::getInstance()->isJoined())  
    {
        ESP_LOGI(TAG,"Short Press detected but device is join to zigbee network, nothing to do");
    } else {
         ZbNode::getInstance()->joinNetwork();
    }
}

//Static
void Main::longPressHandler(void *handler_args, esp_event_base_t base, int32_t id, void *event_data)
{

    ESP_LOGV(TAG,"Long Press detected %ld -",id);
    ZbNode::getInstance()->leaveNetwork();

}

// Static
void Main::identifyHandler(uint16_t attrId, void* value)
{
    if(attrId != ESP_ZB_ZCL_ATTR_IDENTIFY_IDENTIFY_TIME_ID)
        return;
    
    ESP_LOGI(TAG,"Identifying time %d",*((uint16_t*)value));
    if (*((uint16_t*)value) !=0)
        ledFlash(50);
    else
        ledFlash(0);
}

//void Main::zbDeviceEventHandler(ZbNode::nodeEvent_t event)
void Main::zbDeviceEventHandler(ZbNode::nodeEvent_t event)
{
    switch(event){
        case ZbNode::JOINED:
            // Device just joined the network
            {
            ledFlash(0);
            // Synchronise RTC clock of the device
            _timeClient->syncRTC();
            // Wait for the clock to be synchronized (retry every seconds)
            _checkRTCSync = new PeriodicSoftTask(&Main::checkRTCSync, this, 500);
            }
            break;
        case ZbNode::JOINING:
            ledFlash(FAST_BLINK);
            break;
        case ZbNode::NLME_STATUS:
            if(_zbDevice->isJoined()) 
                ledFlash(0);
            else 
                ledFlash(50); //very short flash
            break;
        case ZbNode::LEAVING:
            ledFlash(50);
            break;
        case ZbNode::LEFT:
            ledFlash(-1);
            break; 
        default:
            ESP_LOGW(TAG,"Device Event Handler, event %d not registered occured", 
                        static_cast<uint>(event));
            break;
    }
  
}

void Main::checkRTCSync(){
    if(_timeClient->isSynchronized()){

        ESP_LOGV(TAG,"Clock is sync - triggering action on RTC");

        delete _checkRTCSync;
        _checkRTCSync = nullptr;
    }
}


void Main::setup(void)
{
    ESP_LOGI(TAG,"---------- Setup ----------");

    _button.enablePullup();
    _buttonTask = new ButtonTask (_button);
    _buttonTask->setShortPressHandler(&shortPressHandler);
    _buttonTask->setLongPressHandler(&longPressHandler,(void*)this);

    // switch off led on UART1 as it is not used
    _tx1.on();
    _rx1.enablePullup();
    _rts1.off();

    _aldes = new AldesDriver();


    ESP_LOGI(TAG,"Creating Zigbee device");
    _zbDevice = ZbNode::getInstance();
    _zbDevice->registerNodeEventHandler(&Main::zbDeviceEventHandler, this);

    // Endpoints Construct ////////////////////////////////////////////////
    ZbEndPoint* generalEp = new ZbEndPoint(CONFIG_GENERAL_EP, 
                            ESP_ZB_HA_METER_INTERFACE_DEVICE_ID);
    
    ZbEndPoint* intakeOutEp = new ZbEndPoint(CONFIG_INTAKE_OUT_EP, 
                            ESP_ZB_HA_SIMPLE_SENSOR_DEVICE_ID);

    ZbEndPoint* extractInEp = new ZbEndPoint(CONFIG_EXTRACT_IN_EP, 
                            ESP_ZB_HA_SIMPLE_SENSOR_DEVICE_ID);
    
    ZbEndPoint* supplyInEp = new ZbEndPoint(CONFIG_SUPPLY_IN_EP, 
                            ESP_ZB_HA_SIMPLE_SENSOR_DEVICE_ID);
    
    ZbEndPoint* exhaustOutEp = new ZbEndPoint(CONFIG_EXHAUST_OUT_EP, 
                            ESP_ZB_HA_SIMPLE_SENSOR_DEVICE_ID);

    
    // Clusters Construct ////////////////////////////////////////////////
    ZbBasicCluster* basicCl = new ZbBasicCluster(false,
                        ESP_ZB_ZCL_BASIC_ZCL_VERSION_DEFAULT_VALUE,
                        (uint8_t)0x01);
    basicCl->addAttribute(ESP_ZB_ZCL_ATTR_BASIC_MANUFACTURER_NAME_ID,
                        (void*)MANUFACTURER_NAME);
    basicCl->addAttribute(ESP_ZB_ZCL_ATTR_BASIC_MODEL_IDENTIFIER_ID,
                        (void*)MODEL_IDENTIFIER);


    _otaCluster = new ZbOtaClusterClient(CONFIG_OTA_TIMER_QUERY,
                                        CONFIG_HARDWARE_VERSION,
                                        CONFIG_MAX_DATA_SIZE);
    

    // Temperatures
    _TIntakeOut     = new TSensorCluster();
    _TExtractIn     = new TSensorCluster();
    _TSupplyIn      = new TSensorCluster();
    _TExhaustOut    = new TSensorCluster();

    _filterTimerCluster     = new FilterTimerCluster(_aldes);
    _tBypassCluster         = new BypassCluster(_aldes);
    _setPointCluster        = new SetPointCluster(_aldes);
    
    _airflowMVECluster      = new AirflowCluster();
    _airflowMVICluster      = new AirflowCluster();

    _flowSettingsCluster    = new FlowSettingsCluster(_aldes);

    //_aldes->registerAldesHandler(&SetPointCluster::setDemandPoint, 
    //                    _setPointCluster,AldesModbus::REG_DEMAND_USER);
    _aldes->registerAldesHandler(&SetPointCluster::setCurrentLevel, 
                        _setPointCluster,AldesModbus::REG_CURRENT_LEVEL);

    _aldes->registerAldesHandler(&TSensorCluster::setTemperatureMeasuredValue, 
                        _TIntakeOut, AldesModbus::REG_T_INTAKE_AIR_OUT);
    _aldes->registerAldesHandler(&TSensorCluster::setTemperatureMeasuredValue, 
                        _TExtractIn, AldesModbus::REG_T_EXTRACT_AIR_IN);
    _aldes->registerAldesHandler(&TSensorCluster::setTemperatureMeasuredValue, 
                        _TSupplyIn, AldesModbus::REG_T_SUPPLY_AIR_IN);
    _aldes->registerAldesHandler(&TSensorCluster::setTemperatureMeasuredValue, 
                        _TExhaustOut, AldesModbus::REG_T_EXHAUST_AIR_OUT);
    
    _aldes->registerAldesHandler(&FilterTimerCluster::setFilterTempo, 
                        _filterTimerCluster,AldesModbus::REG_TEMPO_FILTER);
    _aldes->registerAldesHandler(&FilterTimerCluster::setFilterTimerValue, 
                        _filterTimerCluster,AldesModbus::REG_FILTER_STATE_DAYS);
    
    _aldes->registerAldesHandler(&BypassCluster::setBypassTemperature, 
                        _tBypassCluster,AldesModbus::REG_T_BYPASS_SUMMER);
    _aldes->registerAldesHandler(&BypassCluster::setBypassPosition, 
                        _tBypassCluster,AldesModbus::REG_BYPASS_POSITION);
    _aldes->registerAldesHandler(&BypassCluster::setSeasonDetected, 
                        _tBypassCluster,AldesModbus::REG_SEASON_DETECTION);
    
    _aldes->registerAldesHandler(&AirflowCluster::setAirflow, 
                        _airflowMVECluster,AldesModbus::REG_AIRFLOW_MVE);
    _aldes->registerAldesHandler(&AirflowCluster::setAirflow, 
                        _airflowMVICluster,AldesModbus::REG_AIRFLOW_MVI);
    
    _aldes->registerAldesHandler(&FlowSettingsCluster::setVacationLevel, 
                        _flowSettingsCluster,AldesModbus::REG_SETTING_MVE_VACATION);
    _aldes->registerAldesHandler(&FlowSettingsCluster::setDailyLevel, 
                        _flowSettingsCluster,AldesModbus::REG_SETTING_MVE_DAILY);
    _aldes->registerAldesHandler(&FlowSettingsCluster::setPushButtonLevel, 
                        _flowSettingsCluster,AldesModbus::REG_SETTING_MVE_PUSH_BUTTON);
    _aldes->registerAldesHandler(&FlowSettingsCluster::setBoostLevel, 
                        _flowSettingsCluster,AldesModbus::REG_SETTING_MVE_BOOST);
    _aldes->registerAldesHandler(&FlowSettingsCluster::setMaxSpeedLevel, 
                        _flowSettingsCluster,AldesModbus::REG_SETTING_MVE_MAX_SPEED); 


    _timeClient = new ZbTimeClusterClient();

    ESP_LOGI(TAG,"---------------- Register ------------------------");
    
    ZbIdentifyCluster* identifyServer = new ZbIdentifyCluster();
    //ZbIdentifyCluster* identifyClient = new ZbIdentifyCluster(true);

    
    // Attaching Clusters  ////////////////////////////////////////////////
    generalEp->addCluster(identifyServer);
    generalEp->addCluster(basicCl);
    generalEp->addCluster(_timeClient);
    generalEp->addCluster(_filterTimerCluster);
    generalEp->addCluster(_flowSettingsCluster);
    generalEp->addCluster(_tBypassCluster);
    generalEp->addCluster(_setPointCluster);
    //generalEp->addCluster(_otaCluster);

    //intakeOutEp->addCluster(identifyServer2);
    intakeOutEp->addCluster(_TIntakeOut);

    //extractInEp->addCluster(identifyServer3);
    extractInEp->addCluster(_TExtractIn);
    extractInEp->addCluster(_airflowMVECluster);


    //supplyInEp->addCluster(identifyServer4);
    supplyInEp->addCluster(_TSupplyIn);
    supplyInEp->addCluster(_airflowMVICluster);
    
    //exhaustOutEp->addCluster(identifyServer5);
    exhaustOutEp->addCluster(_TExhaustOut);


    // Attaching Enpoints  ////////////////////////////////////////////////
    _zbDevice->addEndPoint(*generalEp);
    _zbDevice->addEndPoint(*intakeOutEp);
    _zbDevice->addEndPoint(*extractInEp);
    _zbDevice->addEndPoint(*supplyInEp);
    _zbDevice->addEndPoint(*exhaustOutEp);
    
    // Get task handles from tasks names
    _eventLoopHandle = xTaskGetHandle( "ZbEventLoop" );
    _xButtonHandle = xTaskGetHandle( "button_task" ); 
    _mbHandle = xTaskGetHandle( "mbc_ser_master" ); 
    
    ESP_LOGI(TAG,"---------------- Starting ZbDevice ------------------------");
    //_zbDevice->setReadyCallback(initWhenJoined);
    
    //ZbApsData* inst = ZbApsData::getInstance();
    _zbDevice->start();

    vTaskDelay(pdMS_TO_TICKS(7000));

    _aldes->start(CONFIG_VMC_POLLING_MS, CONFIG_VMC_POLLING_GEN_DATA);

}



void Main::run(void)
{
    ESP_LOGV(TAG,"Modbus task high water mark %d", 
                            uxTaskGetStackHighWaterMark(_mbHandle ));
    ESP_LOGV(TAG,"Main task high water mark %d", 
                            uxTaskGetStackHighWaterMark(NULL));

    ESP_LOGV(TAG,"Event Loop task high water mark %d", 
                            uxTaskGetStackHighWaterMark(_eventLoopHandle));
    
    ESP_LOGV(TAG,"Button task high water mark %d", uxTaskGetStackHighWaterMark(_xButtonHandle));
    ESP_LOGV(TAG,"Zigbee task high water mark %d", 
                            uxTaskGetStackHighWaterMark(_zbDevice->getZbTask()));


    vTaskDelay(pdMS_TO_TICKS(2000));

   //ESP_LOGD(TAG,"App is running");
    
}


extern "C" void app_main(void)
{
    App.setup();

    while (true)
    {
        App.run();
    }    

    //should not reach here
}

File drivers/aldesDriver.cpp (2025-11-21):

/*
  zVMC
  Repository: https://github.com/akira215/
  License: GNU GENERAL PUBLIC LICENSE Version 3, 29 June 2007
  Author: Akira Shimahara
*/

#define LOG_LOCAL_LEVEL ESP_LOG_VERBOSE
#include <esp_log.h> // TODEL development purpose

#include "scheduledTask.h"
#include "aldesDriver.h"
#include "aldesModbus.h"
#include "zbNode.h"

static const char *ALDES_TAG = "AldesDriver";



// Event handler for periodic soft task
void AldesDriver::query_device_fast()
{
    ESP_LOGI(ALDES_TAG, "Reading current state");
    getBypassPosition();
    getTemperaturesAndFanSpeed();
    getCurrentState();

}

// Event handler for periodic soft task
void AldesDriver::query_device_slow()
{
    ESP_LOGI(ALDES_TAG, "Reading low parameters");

    getRegulationParams();
    getFilterTimerState();  //
    getSeasonDetection();  
    getSpeedSettings();
    getTBypassSummer();
}


// Constructor
AldesDriver::AldesDriver()
{
     _mb_master = new ModbusMaster((mb_comm_mode_t)CONFIG_MB_COMM_MODE, 
                                (uart_port_t)CONFIG_MB_UART_PORT_NUM,
                                CONFIG_MB_UART_TXD,
                                CONFIG_MB_UART_RXD,
                                CONFIG_MB_UART_RTS,
                                CONFIG_MB_UART_CTS,
                                CONFIG_MB_UART_BAUD_RATE,
                                (uart_word_length_t)CONFIG_MB_UART_DATA_BITS,
                                (uart_parity_t)CONFIG_MB_UART_PARITY,
                                (uart_stop_bits_t)CONFIG_MB_UART_STOP_BITS,
                                1000,
                                (uart_mode_t)CONFIG_MB_UART_MODE);
}

AldesDriver::~AldesDriver()
{
    stop();
}
////////////////////////////////////////////////////////////////////////////////////////////

void AldesDriver::start(uint64_t poll_fast_ms, uint64_t poll_slow_s)
{
    query_global_infos(); // warning this will retry automatically 
       
    getDate();
    getErrorCode(); // TODO When do we want to check this

    getTBypassSummer();// TODO When do we want to check this Set as well

    setUserLevel(3);
    _fastPollTask = new PeriodicSoftTask(&AldesDriver::query_device_fast, 
                            this, poll_fast_ms, "aldesFast");
    
    _slowPollTask = new PeriodicSoftTask(&AldesDriver::query_device_slow, 
                            this, poll_slow_s * 1000, "aldesSlow");

    
    ///////////////////// TODEL 
    //ScheduledTask* testTask = new ScheduledTask(&AldesDriver::setFilterTimer, this, 
    //                                        10000, std::string("testFilters"), true, (uint16_t)10);
    
}

void AldesDriver::stop(void)
{
    if(_fastPollTask)
        delete _fastPollTask;
    if(_slowPollTask)   
        delete _slowPollTask;
        
    _fastPollTask = nullptr;
    _slowPollTask = nullptr;
}
////////////////////////////////////////////////////////////////////////////////////////////

void AldesDriver::query_global_infos()
{
    bool res = true;
    res = res && getDeviceInfos(); 
    res = res && getFanConfig();
    res = res && getSpeedSettings();
    res = res && getRegulationParams();

    if(!res) // TODO deal with error on previous methods
        ScheduledTask* retryTask = new ScheduledTask(&AldesDriver::query_global_infos, 
                                            this, 60000, 
                                            std::string("aldesRetry"));

}
////////////////////////////////////////////////////////////////////////////////////////////

bool AldesDriver::getDeviceInfos()
{
    mb_data gen_data = _mb_master->readRegisters(AldesModbus::MB_ALDES_ADDR,
                                            AldesModbus::REG_PRODUCT_CODE,
                                            6);
                                        
    if (gen_data.getSize() > 0)
        _data.product_code = gen_data;

    ESP_LOGD(ALDES_TAG, "Product Code : %d - %s", 
                    _data.product_code, aldesDeviceFromCode(_data.product_code));

    _data.serial_num = gen_data.getDataFrom(4);

    ESP_LOGD(ALDES_TAG, "Serial Number : %d ", _data.serial_num);

    mb_data firm_ver = _mb_master->readRegisters(AldesModbus::MB_ALDES_ADDR,
                                            AldesModbus::REG_SOFT_VERSION,
                                            1);
    if (firm_ver.getSize() > 0)
        _data.firm_ver = firm_ver;

    ESP_LOGD(ALDES_TAG, "Firmware version : %d", _data.firm_ver);

    if ((_data.product_code == 0xffffffff) ||
            (_data.serial_num == 0xffffffffffffffff)||
            (_data.firm_ver== 0xffff))
            return false;

    return true;
    
}

////////////////////////////////////////////////////////////////////////////////////////////
bool AldesDriver::getSpeedSettings()
{
    mb_data speed_settings = _mb_master->readRegisters(AldesModbus::MB_ALDES_ADDR,
                                            AldesModbus::REG_SETTING_MVE_VACATION,
                                            10);
                                        
    if (speed_settings.getSize() > 0)
    {
        _data.setting_MVE_vacation   = speed_settings;
        _data.setting_MVI_vacation   = speed_settings.getDataFrom(2);
        _data.setting_MVE_daily      = speed_settings.getDataFrom(4);
        _data.setting_MVI_daily      = speed_settings.getDataFrom(6);
        _data.setting_MVE_pushButton = speed_settings.getDataFrom(8);
        _data.setting_MVI_pushButton = speed_settings.getDataFrom(10);
        _data.setting_MVE_boost      = speed_settings.getDataFrom(12);
        _data.setting_MVI_boost      = speed_settings.getDataFrom(14);
        _data.setting_MVE_maxSpeed   = speed_settings.getDataFrom(16);
        _data.setting_MVI_maxSpeed   = speed_settings.getDataFrom(18);

        postEvent(AldesModbus::REG_SETTING_MVE_VACATION, (int16_t)(_data.setting_MVE_vacation));
        postEvent(AldesModbus::REG_SETTING_MVE_DAILY, (int16_t)(_data.setting_MVE_daily));
        postEvent(AldesModbus::REG_SETTING_MVE_PUSH_BUTTON, (int16_t)(_data.setting_MVE_pushButton));
        postEvent(AldesModbus::REG_SETTING_MVE_BOOST, (int16_t)(_data.setting_MVE_boost));
        postEvent(AldesModbus::REG_SETTING_MVE_MAX_SPEED, (int16_t)(_data.setting_MVE_maxSpeed));
    }
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

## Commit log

2025-10-04 First Commit PCB
    [2025-10-03 Comput.ods, partitions.csv, zMod_PCB.csv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]
2025-10-07 Updating Mouser BOM adue to Maxim supply restrictions
    [zMod_PCB_Mouser.ods]
2025-10-14 adding 3D printing enclosure
    [zMod_enclosure-Button.stl, zMod_enclosure-Enclosure_Top.3mf, zMod_enclosure-Enclosure_Top.stl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]
2025-10-18 Implementing aldes driver
2025-10-19 starting algo aldes driver
2025-10-20 working on aldes driver
    [partitions.csv]
2025-10-25 Temperatures clusters ok
2025-10-26 working on tempo filter
2025-11-13 add custom filter attr
2025-11-15 custom attr for filters
2025-11-15 Filter tempo working full
2025-11-15 Filter cluster full ok
2025-11-21 Sharing docs
    [2020.10.09 TableModbus_Nükub_B120.xlsx, 2023-07-05 Programmation VMC.xlsx]
2026-05-28 Add min and max values for Filter_Elapsed_Days
